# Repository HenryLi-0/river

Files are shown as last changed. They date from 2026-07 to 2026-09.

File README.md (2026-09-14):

<div align="center">
    <h2>River</h2>
    <p>by <a href= "https://github.com/HenryLi-0/river"> @HenryLi-0 </a></p>
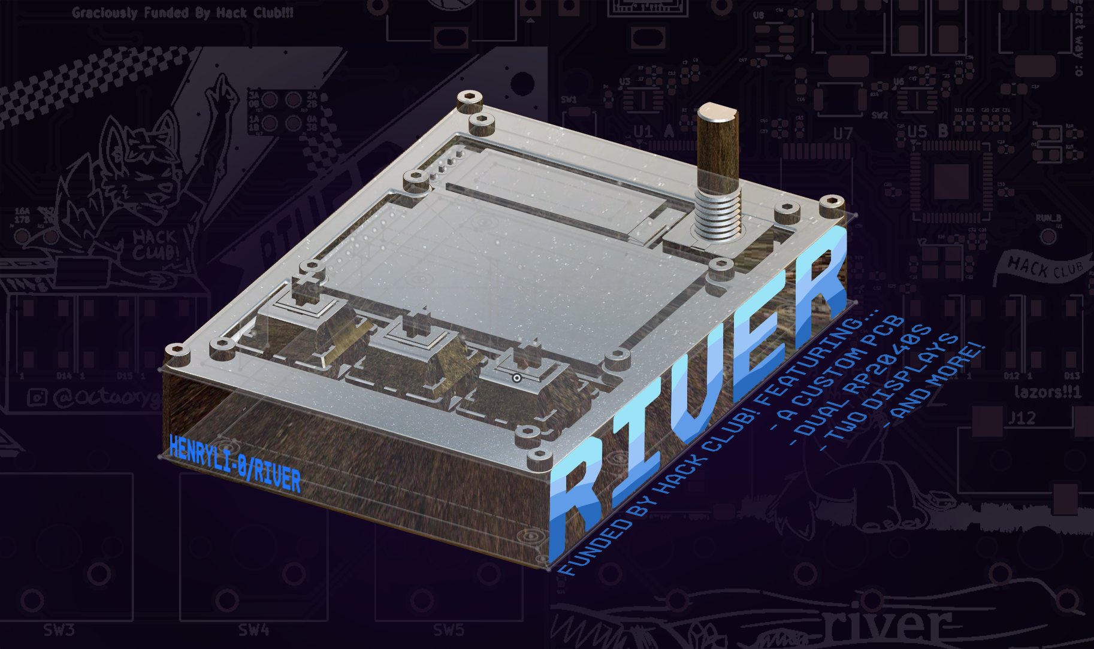
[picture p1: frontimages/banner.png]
banner
    
</div>

<sub>All designs are open source! Hardware licensed under CERN OHL S v2.<sub>

# River

a quick stepping stone

---

## What this?

A couple of months ago, after listening to [archived](https://archive.org/details/the-sport-saver?webamp=default) [music](https://archive.org/details/under-the-ground?webamp=default) on the Internet Archive with Webamp, I thought the graphics on the right side (powered by Milkdrop) were pretty cool. I've always liked how Geometry Dash levels *typically* have well synced gameplay, since it's just so satisfying. Additionally, I also dislike how everything is switching to streamsing services (both because of the subscription model and more importantly the amount of cellular data it uses lol), so I basically wanted to bring music-synced graphics onto a portable offline device!

So, River is a relatively small PCB, hosting a dual RP2040 setup, each having custom firmware! The first one handles all the user controls, file loading, and the audio jack, while the second handles the display math, communicating with the first RP2040 by SPI and UART. Through this (rather unconventional) setup, audio can play continously while the second RP2040 works on more taxing graphics using the Pico SDK for C, with the second RP2040 basically just doing the graphics. It does this by having a PCM5101A and a TPA6132A2RTE into a TRS audio jack!

In retrospect, this project wasn't exactly a quick stepping stone (as in, it took over fifty hours of development), but it sure did review many topics surrounding PCB design with KiCAD, building on to what I learned from Hackpad and Raven! Originally, this was in case [fermion](http://github.com/HenryLi-0/fermion) would require a custom PCB, but who knows if it'll need one in the end. Anyways, working on River did teach a lot, as well as letting me have fun creating art for it!

---

Huge thanks to [this](https://blueprint.hackclub.com/starter-projects/devboard) guide from Blueprint and [this](https://pip-assets.raspberrypi.com/categories/814-rp2040/documents/RP-008279-DS-1-hardware-design-with-rp2040.pdf) documentation from Raspberry Pi for valuable information on RP2040 wiring design. Thanks!

---

## Pictures!

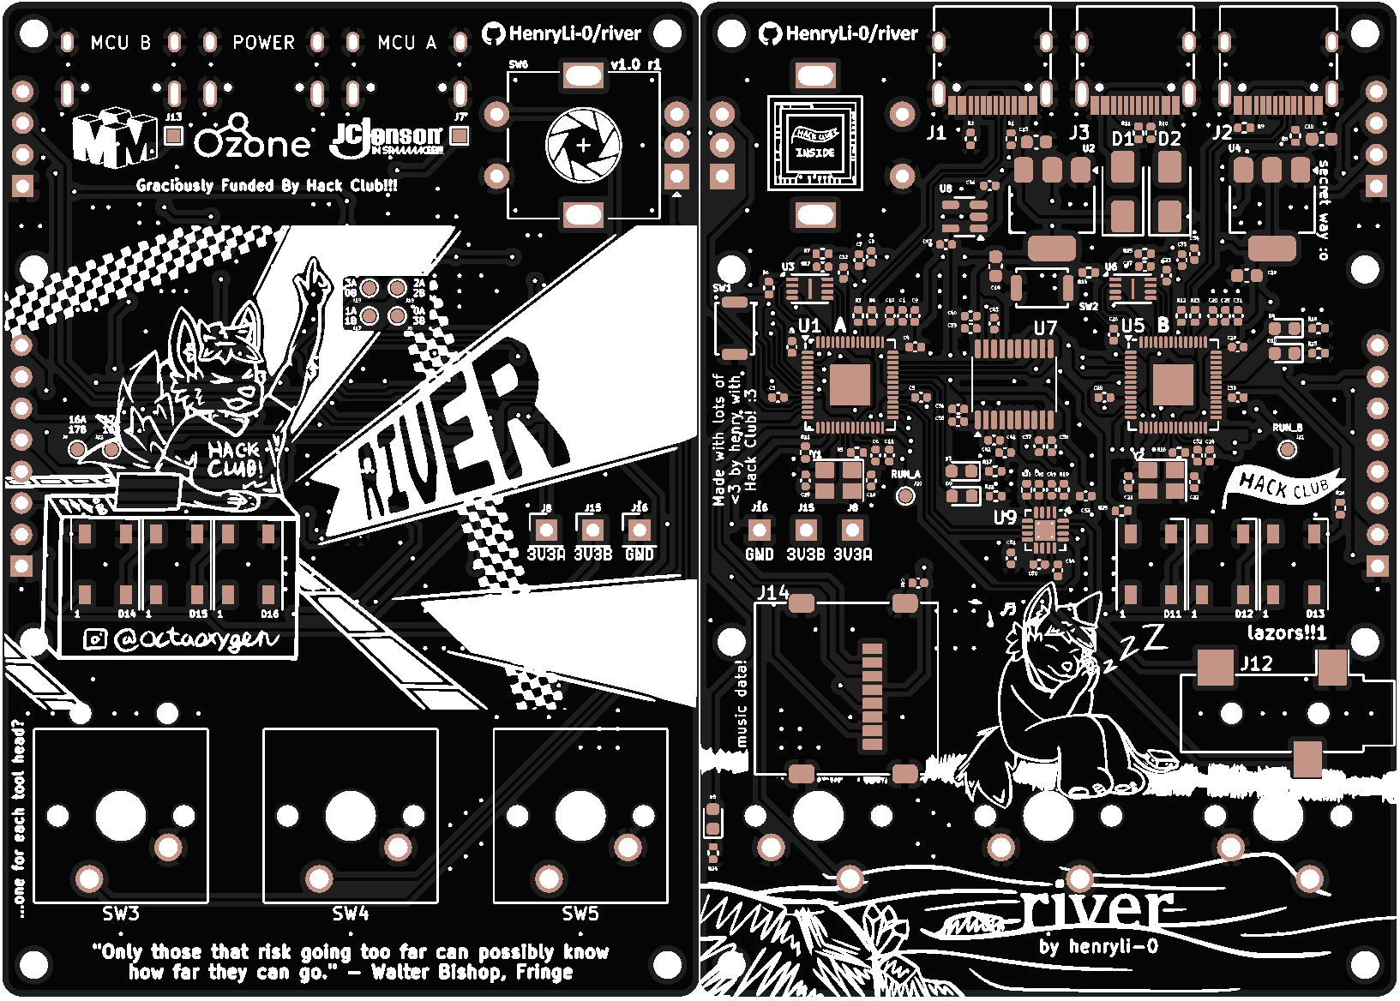
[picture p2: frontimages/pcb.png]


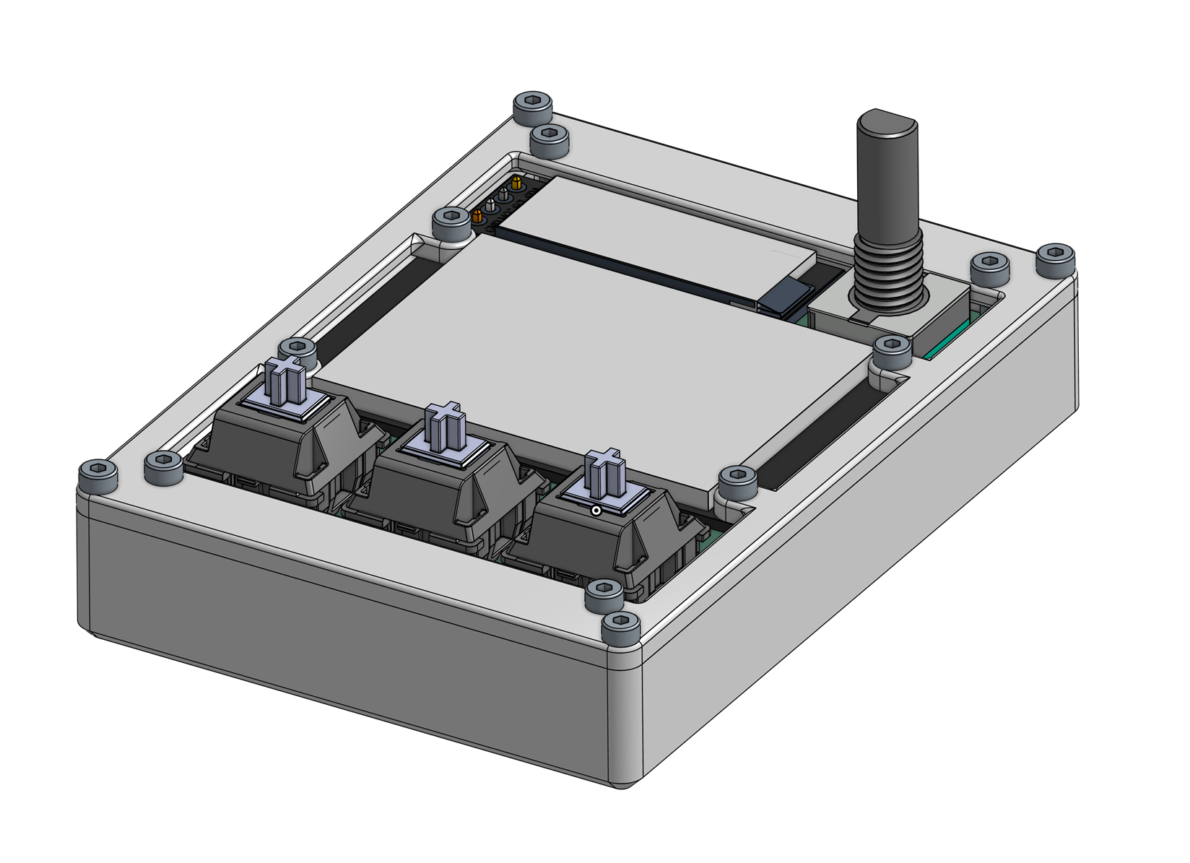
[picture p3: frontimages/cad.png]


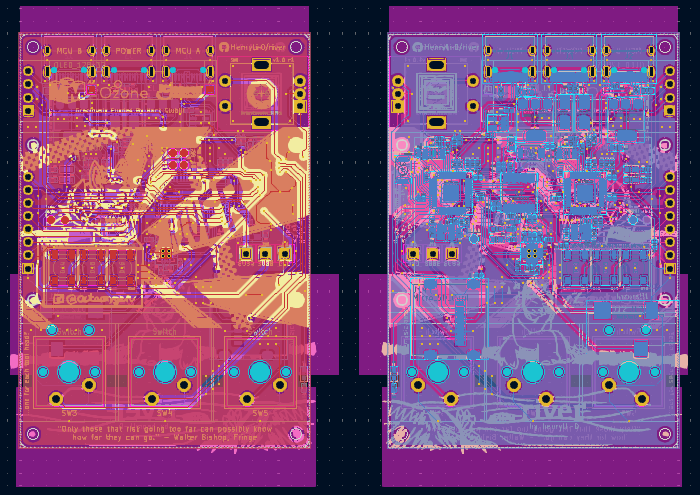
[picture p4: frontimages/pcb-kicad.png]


---

## Directory

- [CAD](</cad/README.md>)
    - The case is made in Onshape!
- [Firmware](</firmware/README.md>)
    - Two firmwares for the two RP2040s!
- [Updatelogs](</updatelogs/>)
    - As always, lots of behind the scenes content! It's also a decently long read as always :D
- [BOM](</BOM.csv>)
    - Want to build one yourself? Here's the BOM in CSV form! However, I suggest using the Google Sheets one, check down below for that!

---

## Usage

Assembly
1. First, one must obtain the PCB! It's not really made for hand-soldering, more so for JLCPCB's or any other PCBA service to assemble (but feel free to give it a try if super experienced!).
2. The main PCB's here? Great! Flash the two RP2040s with their specific firmwares and make sure all status LEDs and storage works! (Same process as testing a devboard, except there's not really any free pins...)
3. Once the RP2040s are confirmed to be in good condition, test the micro SD card slot and the audio jack! A micro SD card and a TRS audio plug (usually in random earbuds) are needed! Load music on and see if it works (after setting the firmware to play a song from the micro SD card).
4. Once those also work, solder on the displays and keys! This should be fairly straightforward, watch a soldering tutorial if needed! (Yes, a soldering iron is also needed!)
5. Assemble everything into the case and screw in the M2 screws! Adjust the case if needed if the audio plug doesn't fit well with the current slot!

---

## BOM

Note: This list was made in mid-September 2026. Depending on a ton of factors, this price may change over time, so these prices may be different! Multiple parts are sourced by me (since I have a bunch of extra parts laying around), so it will likely cost a bit more. Currently, shipping and tax estimates are included (to NYC), check out the `updatelogs` whenever construction occurs to find the actual price it resulted in!

[Here's](https://docs.google.com/spreadsheets/d/1_4eaDKRTe7VvPdyKRilJCp6rfzp3SGLLEaJtn6RHo0M/edit?gid=0#gid=0) the original Google Sheets BOM, color coded too! (It'll also be more updated, but I'll try to sync this one too!)

| Part | Price | Link |
|---|---|---|
| Board PCB (PCBA) | $84.61 | JLCPCB |
| M2 Screws (16mm, 50pcs) | $1.41 | [AliExpress](https://www.aliexpress.us/item/3256804341271555.html) |
| 128x32 OLED Display (White, 1pc) | $2.44 | [AliExpress](https://www.aliexpress.us/item/3256808453793642.html) |
| 128x160 TFT Display (1.8 inch TFT) | $4.06 | [AliExpress](https://www.aliexpress.us/item/3256807859088652.html) |
| WS2812B LEDs (3) | $0.00 | Anywhere |
| Micro SD Card (1) | $0.00 | Anywhere |
| EC11 Rotary Encoder (1) | $0.00 | Anywhere |
| Cherry MX Switch (3) | $0.00 | Anywhere |
| Estimated Shipping (JLCPCB to NYC) | $11.05 | JLCPCB |
| Estimated Shipping (AliExpress to NYC) | $0.00 | AliExpress |
| Buffer | $5.00 | |
| TOTAL | $108.57 | |

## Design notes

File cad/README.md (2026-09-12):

# CAD

Check out the CAD, made in Onshape, over [here](https://cad.onshape.com/documents/62a670f78dfbc39c10baf690/w/2a64289aedb28fbfcb5cf3fe/e/198c185c06bddf69967ad1b8)! The `.STEP` file is also in this directory, if needed! (Note that the Onshape document will be more updated! The export date for the file is in the name!)

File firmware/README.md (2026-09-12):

# Firmware

As always, firmware is kinda difficult to write without the actual board to rapidly test, but here's a couple test and concepts for the actual firmware!

*Note: As of mid-September 2026, these firmwares are incomplete for previously mention reasons! (If you're somehow reading this, this would be a fun challenge to do if you're up to it! It's fairly straightforward if you have the parts!)*
- [MCU_A](</firmware/mcu_a/README.md>)
    - `MCU A` firmware! This is the one that does the controls and audio stuff!
- [MCU_B](</firmware/mcu_b/README.md>)
    - `MCU B` firmware! This is the one that does the big display stuff!
- [Test](</firmware/test/>)
    - Lots of test firmwares, good for testing stuff!

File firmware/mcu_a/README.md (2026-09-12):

# MCU A

This RP2040 is responsible for managing user inputs, the smaller display, loading and playing music, as well as transmitting song information to `MCU B`!

Here's the pins:
- 0-3: SPI0 MCU
- 4-10: Buttons
- 11-14: Micro SD Card
- 16-17: UART0 MCU (backup)
- 18-19: OLED 128x32 Display
- 23-25: RGB, Board, Boot LEDS
- 20-22, 26-28: Audio

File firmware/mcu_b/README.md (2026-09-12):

# MCU B

This RP2040 is responsible for displaying the graphics on the central display, after receiving song information to `MCU A`!

Here's the pins:
- 0-3: SPI0 MCU
- 8-13: LCD 128x160 Display
- 16-17: UART0 MCU (backup)
- 23-25: RGB, Board, Boot LEDS

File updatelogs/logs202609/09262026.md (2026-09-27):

# 9/26/2026 - 21st Update!

welcome back! yes, i know, fermion hasnt gotten an update in like two days, but hey, we're back for a bit here! why?

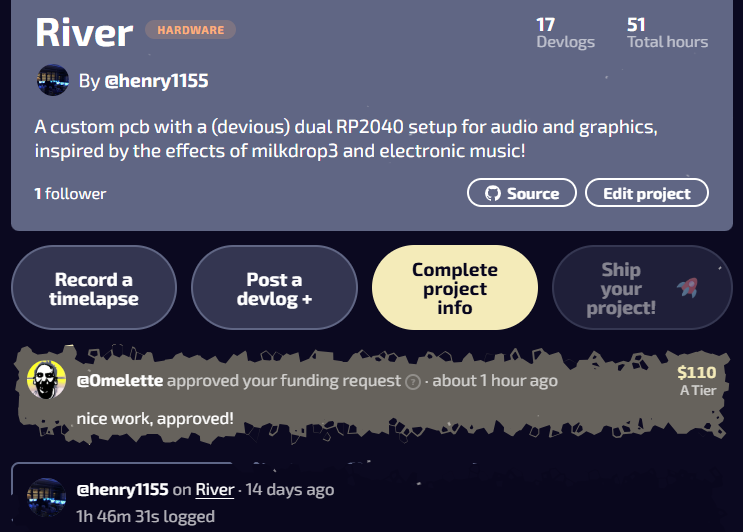
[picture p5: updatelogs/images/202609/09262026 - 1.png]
woo


as always, this means i gotta lock in and get the stuff ordered today! (originally i saw the picture like 6 minutes after it came out, but i had to do a little work before getting here!)

well, it's actually 6:52 PM at 9/26/2026 now, that stuff up there was from yesterday night, i just didnt start last night. anyways, here we go! (additionally, i think i know why my hand hurts now, turns out slamming your hand into the table is not a good idea)

anyways, ordering time

so uh. jlcpcb. why is the summary page different from the checkout page by >$40. 

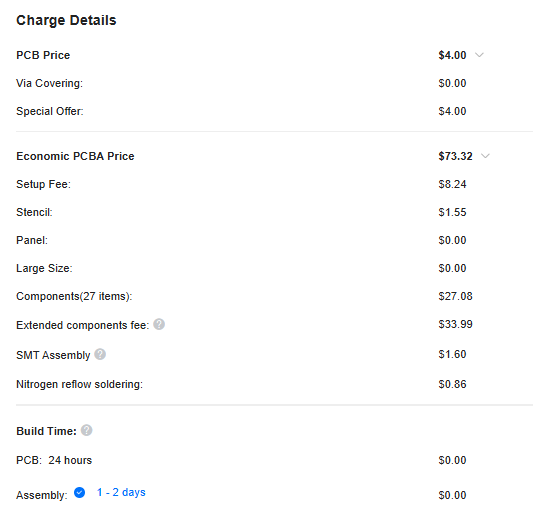
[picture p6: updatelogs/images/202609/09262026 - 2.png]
erm


optimizng bom part 2

ok, it's 7:36 PM, this isnt gonna work, brb.

yeah, so idk what to do now. like, theres literally not much i can do, i optimized it to be a grand total of $7 less.

since when did global direct shipping line... oh wait thats cm not mm, i was gonna explode for a second

ok, so seems like the goal is to somehow reduce our bom for the pcb itself from $73.32 (already down from like $80 something) to be less than $59 somehow. yeah. thats not really happening...

where did my coupon go

i mean, either way we gotta shave $40 off our bom somehow here. which is very much impossible and not happening.

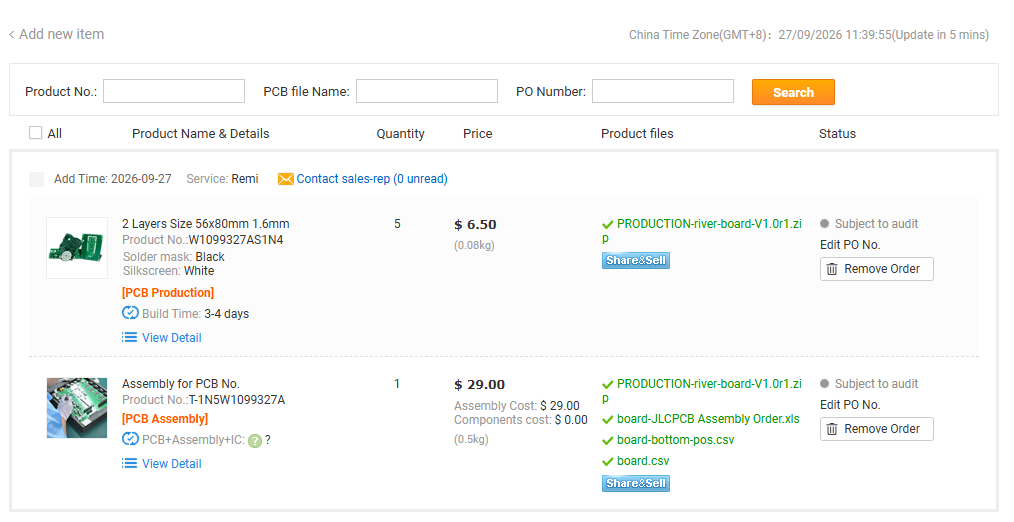
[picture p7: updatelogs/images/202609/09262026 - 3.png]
hmm


ive moved it to pcbway (hopefully), files are under review but im hoping that, even if shipping and customs are still mad high, that at least only have one board assembled will cut enough on price? idk though.

well, that said, see ya in like a week or whenever they review it! it's 11:43 PM and yeah, see ya! ill be over at fermion in a second, so yeah, good night!

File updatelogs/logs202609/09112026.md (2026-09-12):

# 9/11/2026 - 20th Update!

well, it's 10:17 PM, lets get to it!

a while before i updated the background of the banner so its darker and added a glow, thought it made things look a bit better? idk

anyways, bom time, more like everything time, what do we have left to do?

- test code (bare sample)
- cad double check and export
- update bom (add M2 screws, double check)
- ship???

so yeah, let's get that done tonight!

well, you know my main source for all screws :p ([here](https://www.aliexpress.us/item/3256804341271555.html) on aliexpress!)

ok, bom should be good, cad should be good, exporting...

ok, another banner update! it now has the pcb in the background! (faded, of course!)

ok, it's 11:56 PM now, gonna quickly commit, did a ton of docs, readme stuff, bom stuff, basically i think (might be missing something?) mostly everythings ready except for the firmware!

well, tried my best, really cant write the firmware right now, its kinda weird to do it without constantly flashing and testing it (yeah, its not optimal, but still, thats my favorite way to do it)

ok, a bit more clean up work, i think we're ready to ship!

*The rushing torrent of water. It's rushing and rushing, basking below a warm summer sun, except the water keeps rushing, streaming as a tidal wave rather than a river. It's fast, almost unstoppable, gushing as it passes by.*

*The torrent's calming! Quick, swim to the side! And indeed it was. After nearly two months, bobbing, rather, tumbling, through the crashing flow of the waters, it found its rhythm. Swimming to the shore, this adventure, has come to an end, and a considerably unfamiliar land presents itself, much different than the place upstream...*

ok, it's 12:22 AM now, gonna move this to the website so its updated with today's stuff! hope you enjoyed that little bit of writing, and yeah, for now, good night!

hey its 1:13 AM and im back, added some basic firmware stuff so its more than a blinking led, still gotta work on it a bit, also updated the readme with the audio part names but yeah, for now, good night!

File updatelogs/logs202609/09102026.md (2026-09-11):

# 9/10/2026 - 19th Update!

ok, 10:42 PM, wow, we're locked in tonight!

no time to waste, to onshape!

wow got started so fast i forgot to post last updates log to the site, one second... ok, back to onshape!

ok, here it is!

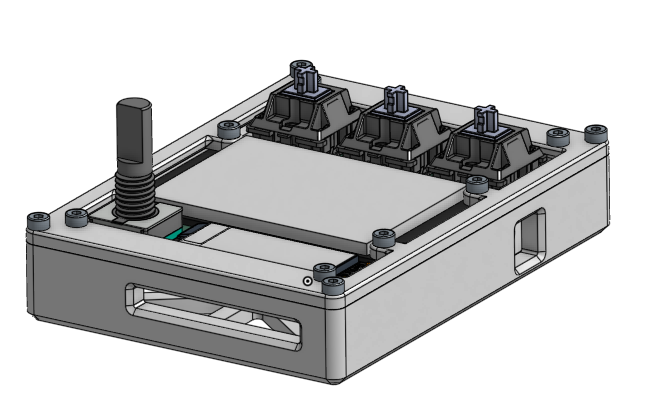
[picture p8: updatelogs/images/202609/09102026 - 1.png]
waw


added the port holes and stuff, did a couple checks, it should be ok? of course, the cad can be adjusted when the actually parts arrive! anyways, exporting stuff so that i can make a thing for this!

so some how i only have 6.7GB of storage left. kinda funny but not very good, ill deal with that later...

ok, good amount of work today! wrapped up the cad work it seems, also did some banner stuff! (check the readme!)

anyways, i think i need another day for this, with that said, it's 12:24 AM, and yeah, good night!

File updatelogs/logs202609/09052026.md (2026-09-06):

# 9/5/2026 - 18th Update!

ok, it's 9:28 PM, they rejected the part request (lel) back on like 8/28/2026, yeah its been a week

anyways, lets finish this one up?

ignore the bottom right corner if youre on lookout, idk if it even records it but i need to watch a video right now

anyways gonna change the sd card footprint thing now

nvm dont need to watch this video i guess

ok, should be replaced, gonna double check it has a model

ok, it does, just came back after a quick half hour break (well thats not quick), 10:40 PM and checking for errors...

ok, 10:56 PM, it should be good! added a couple more vias for ground stuff, gonna commit and prepare to export!

ok, back at 11:38 PM, let's export!

(also for reference [this](https://jlcpcb.com/partdetail/MOLEX-472192001/C164170) is the jlcpcb part for the microsd card) anyways, all exported, doing jlcpcb stuff now!

ok, stuff should be moved over, time to go to placement!

well, seems good now?

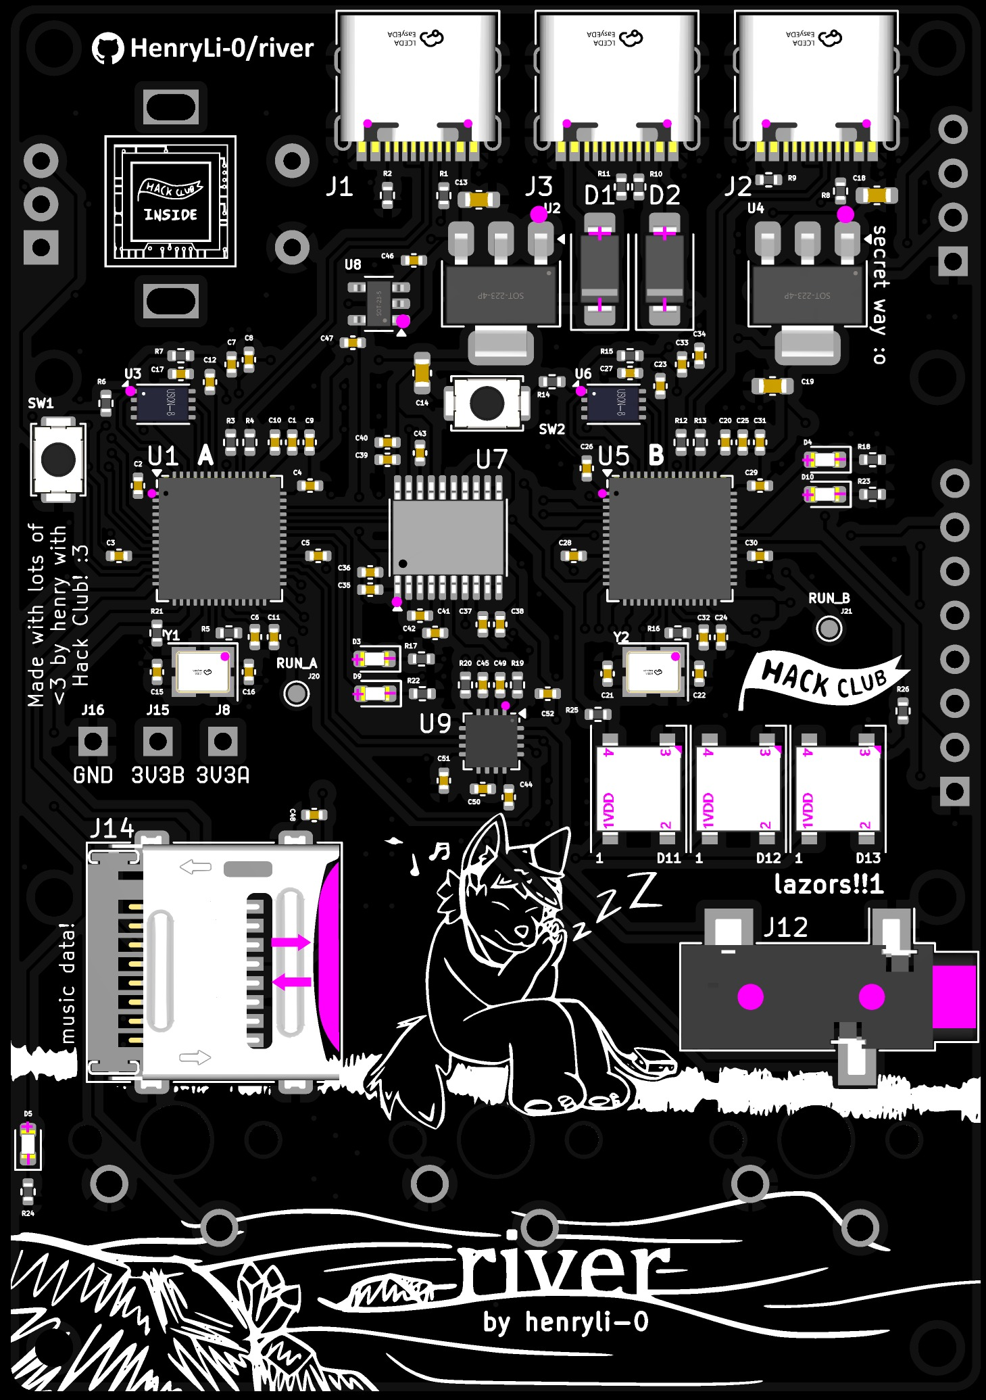
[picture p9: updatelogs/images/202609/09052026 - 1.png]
waw


huh looks like jlcpcb got an update some time recently, anyways, after comparing images, looks good!

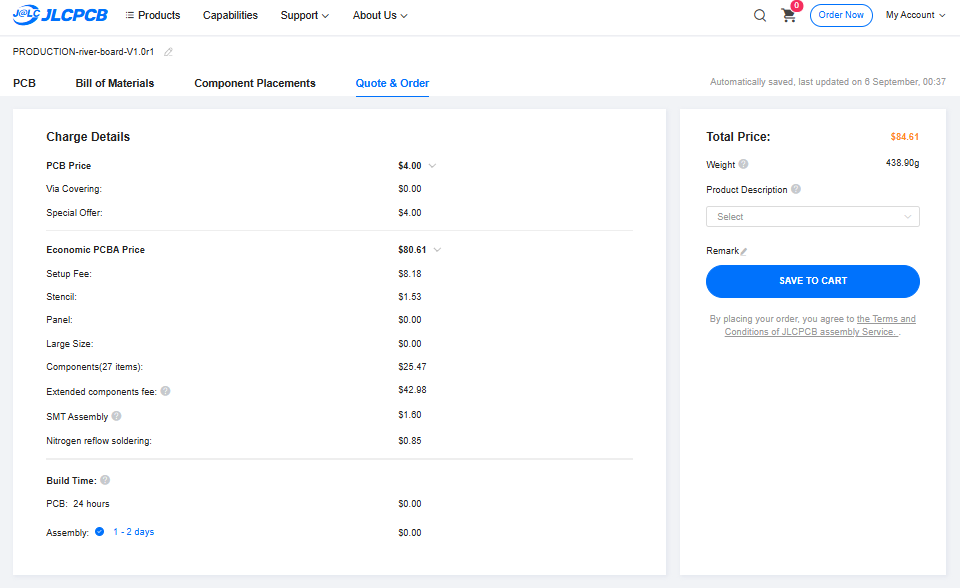
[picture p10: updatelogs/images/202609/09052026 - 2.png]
hmm


hmm

well, ggs! the boards good to go it seems!

quick commit

well, now all we need to do is clean up the repository and prepare to ship! (and some test code, cant really do much right now, of course)

ok its been like half an hour, havent done much, i think im gonna end it here! so yeah, shipping and maybe updating the cad is the only thing really left (oh wait and screws for the bom), so yeah, it's 1:14 AM, good night!

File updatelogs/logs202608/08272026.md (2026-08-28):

# 8/27/2026 - 17th Update!

ok, 10:39 PM, lets speed through this!

ok, quite a bit of rotating stuff on jlcpcb's side, but here it is!

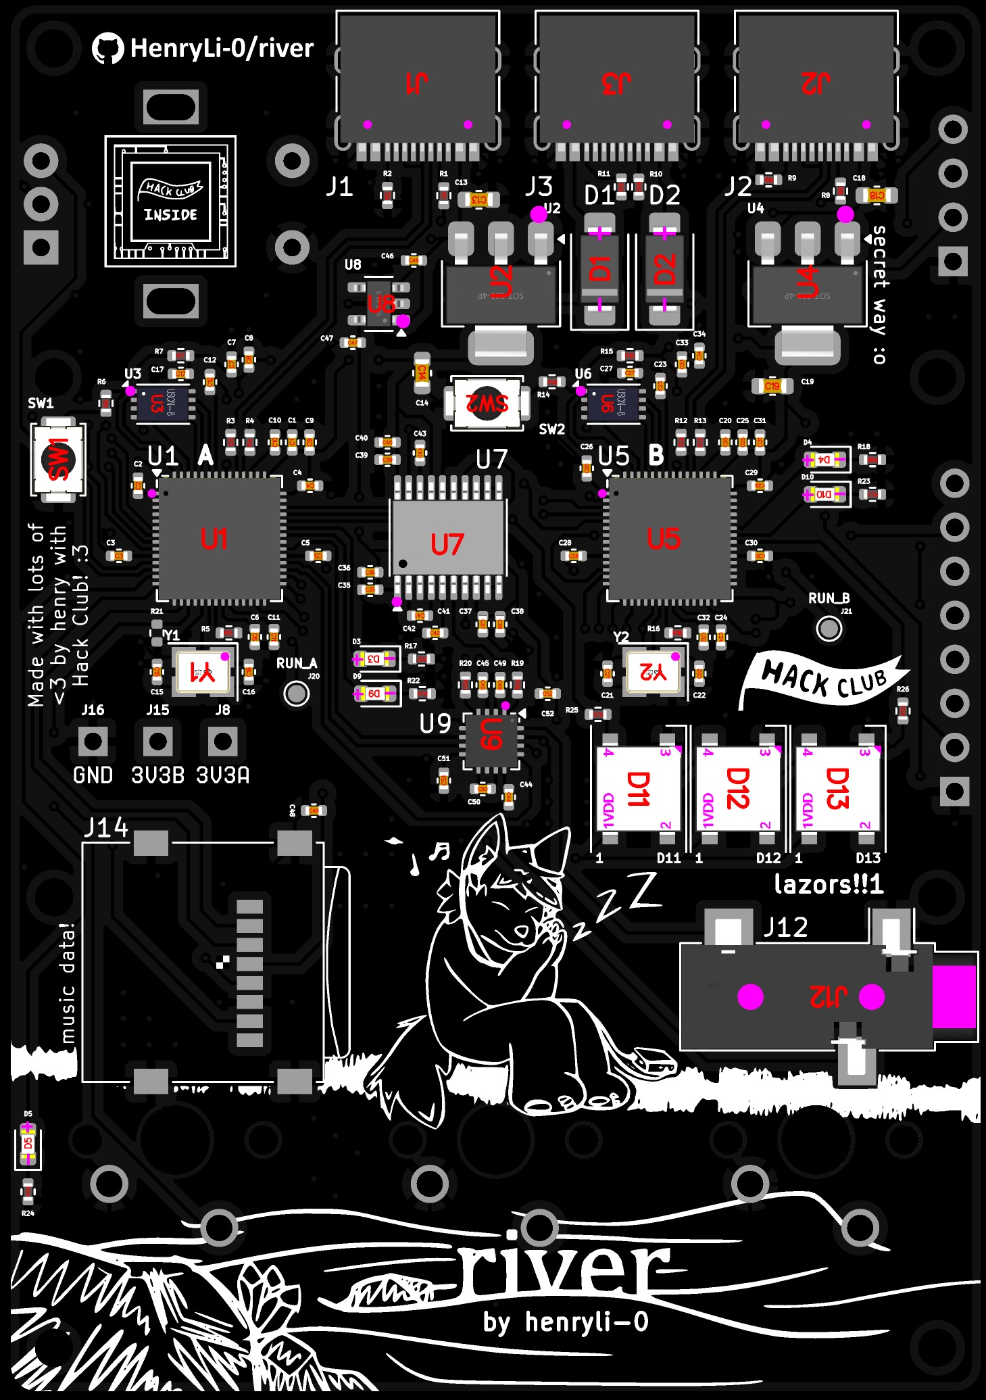
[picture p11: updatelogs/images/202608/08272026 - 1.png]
hmm


it should mostly be good? only thing im not sure of is the crystal but yeah!

hopefully when i reload the page it saves...

no it doesnt. well, thats annoying.

well, 11:21 PM, made an application for the sd card thing to actually get a model, so yeah, not much i can do today, unfortunately? just kididng, cad could use some work, brb

ok, 11:47 PM, im back!

shrunk the middle section from 1.4cm to 0.75cm! nvm its back at 0.95cm, anyways, total height decreased from 2.1cm to 1.5cm! ok, 11:54 PM, brb!

back at 12:44 AM, i guess its a good time to assemble a bom? (for the other parts)

well, 1:07 AM, that wasnt really much... yeah, gotta wait till the 3d model for the micro sd card slot appears or i just gotta replace it, idk, but yeah, i guess ill check tomorrow evening, if its not there, i guess ill just replace it? but yeah, 1:21 AM now (yes i got distracted), so yeah, good night!

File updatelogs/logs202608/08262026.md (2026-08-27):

# 8/26/2026 - 16th Update!

well, welcome back, it's 3:00 PM here in nyc right now, a bit of a warm day, i kinda want to get this done, its taken far too long (its been a month already?). i kinda have more important things to sort out, but they can wait a bit, they're not like extremely time sensitive!

ok, 3:10 PM, im actually back now, ive been considering removing the encoder (yet itll look crazy weird, i know), imo, most features should be still possible without it, just a bit more annoying to navigate with long presses and stuff, idk.

eh, whatever, im gonna first play around with the layout to see if its possible first

ok, audio jack moved to the bottom (and added the 3d model!), lets run drc... uh, suspiciously no error?

quick commit!

had a great idea (flipping the switches upside down for more space)

uh it would probably be better to keep the data lines short right

hold on did i reverse the audio jack direction... anyways, 5:10 PM, micro sd card is there and all drc errors fixed! gonna commit real quick and then run to the bathroom...

ok, 5:38 PM and back!

ok, did a bunch of via stuff so all the grounds are more connected, fixed up some silkscreen text, the only thing really left is to fix the silkscreen art stuff, but yeah!

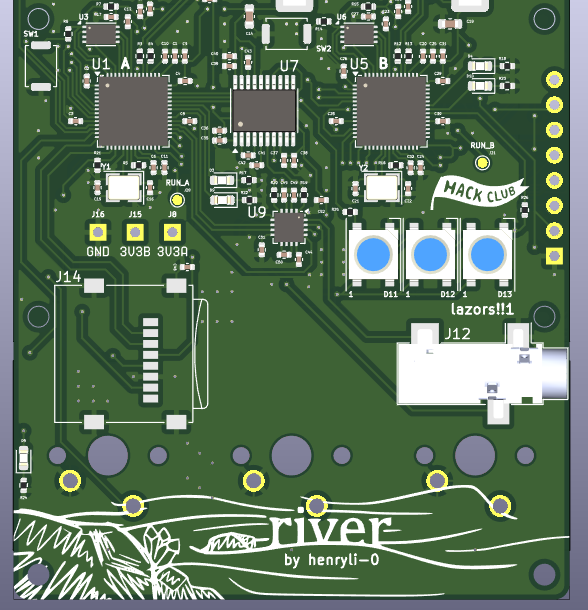
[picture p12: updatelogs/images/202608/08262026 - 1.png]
waw


so yeah! gotta double check that audio jack direction again (it should be correct now?), but yeah, it's 6:33 PM, off to dinner, brb!

9:48 PM, did a good amount of work off camera fixing the silkscreen and stuff, but yeah, pretty happy with where it is now! could probably start exporting stuff now? gonna quickly commit first though...

oh yeah, also checked the length of the traces that should be equal (usb c connections), they're still good!

ok, 11:32 PM, im back for a bit, time to export stuff! (again!)

12:23 AM, lots of part picking, gonna brb!

im back at 1:53 AM, lets quickly finish this up!

i really cant find an led that works. well, had a little help, but C524052 works!!! 

well, that said, it's 2:43 AM, the bom has been exported and should be there, im gonna go to sleep now, gotta wake up earlier tomorrow for something, so yeah, good night!

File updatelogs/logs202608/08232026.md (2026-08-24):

# 8/23/2026 - 15th Update!

so. how much silkscreen art can someone make? turns out, not enough, but i think im at the point where im mostly satisfied with the decoration and the layout, in theory, we can kinda finish everything today? it's 6:01 PM right now in nyc, im just gonna get ready to post yesterday's (well, two days ago's) updatelog onto the website

oh yeah, another cool thing, i figured out how to fix my s key! its staying in there pretty well so far, so let's see how it holds up...

ok, ive posted it there, what do we have left?

- finish the pcb clean up (not much, really, just notes and checks)
- drc again, check its all updated and good
- export and do the jlcpcb stuff, create and calculate bom/prices
- decide whether or not to use female headers for the removable screen
    - on one side is the audio jack, repairability and, well, the art
    - on the other side is increased height and possible connection issues
    - its really just that the audio jack probably doesnt fit
- make the side heights readable (this cad is abysmal)

well, what are we waiting for? let's get to it!

i, in fact, did not lock in. just kidding!

[this](https://www.aliexpress.us/item/2255800687544049.html) looks good for the header stuff i was talking about, id say the screws should also be able to secure everything, so thats another plus!

quick commit, one second

ok, 7:35 PM now, gonna go to dinner now, lots of cad work!

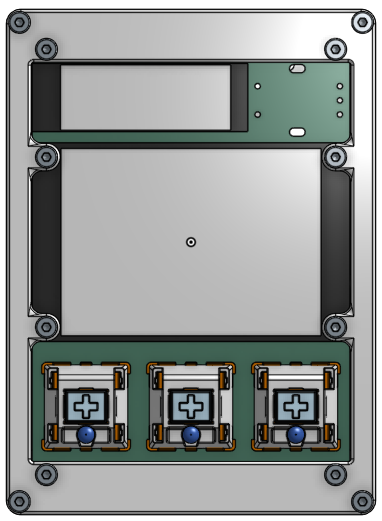
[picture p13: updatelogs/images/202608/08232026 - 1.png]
hmm


ok, see ya in a bit!

back at 10:57 PM, let's just finish this :p

so. i just realized something.

it's not a good realization.

the sd card is on the top.

the microphone jacks is on the top, that's fine, but the sd card holder is on the top. why is this an issue? well, i was particularly avoiding double sided assembly for the costs. and then i forget about this.

i guess we cant avoid it then, 11:44 PM, these docs are confusing

im back at 1:52 AM, im gonna try this again

thanks to [this](https://jlcpcb.com/help/article/how-to-generate-gerber-and-drill-files-in-kicad-8) help article! i guess doing it manually instead of the fabrication toolkit or something back with hackpad was needed...

ok, 2:15 AM, im basically not able to do anything right now. im pretty sure i cant keep going with standard pcba, since it gets crazy expensive (yeah, im trying to not make it super expensive) and it has some weird setup thing that i really dont want to figure out (something about adding extra rails to the side? i mean, thats not optimal here). so yeah, i cant do anything for now. what that means is that i have to do a ton of redesigning, specifically moving the sd card and audio jack to the bottom (maybe ill remove the encoder for it??? who knows), and of course the leds (just kidding, maybe the resistor, but the rest is staying on top! ill just have to do some (abysmal) hand soldering...)

so yeah. that's where things are at, it seems. ill probably have to remove the female pin header row and just direct solder it then? but yeah, that's it for now. well, i guess theres more to do know, it's 2:21 AM, so yeah, good night!

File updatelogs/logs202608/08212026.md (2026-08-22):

# 8/21/2026 - 14th Update!

so... where have i been? it's 10:51 PM, one second...

though it may appear like ive locked out, ive spent like a least three hours drawing the silkscreen stuffs!

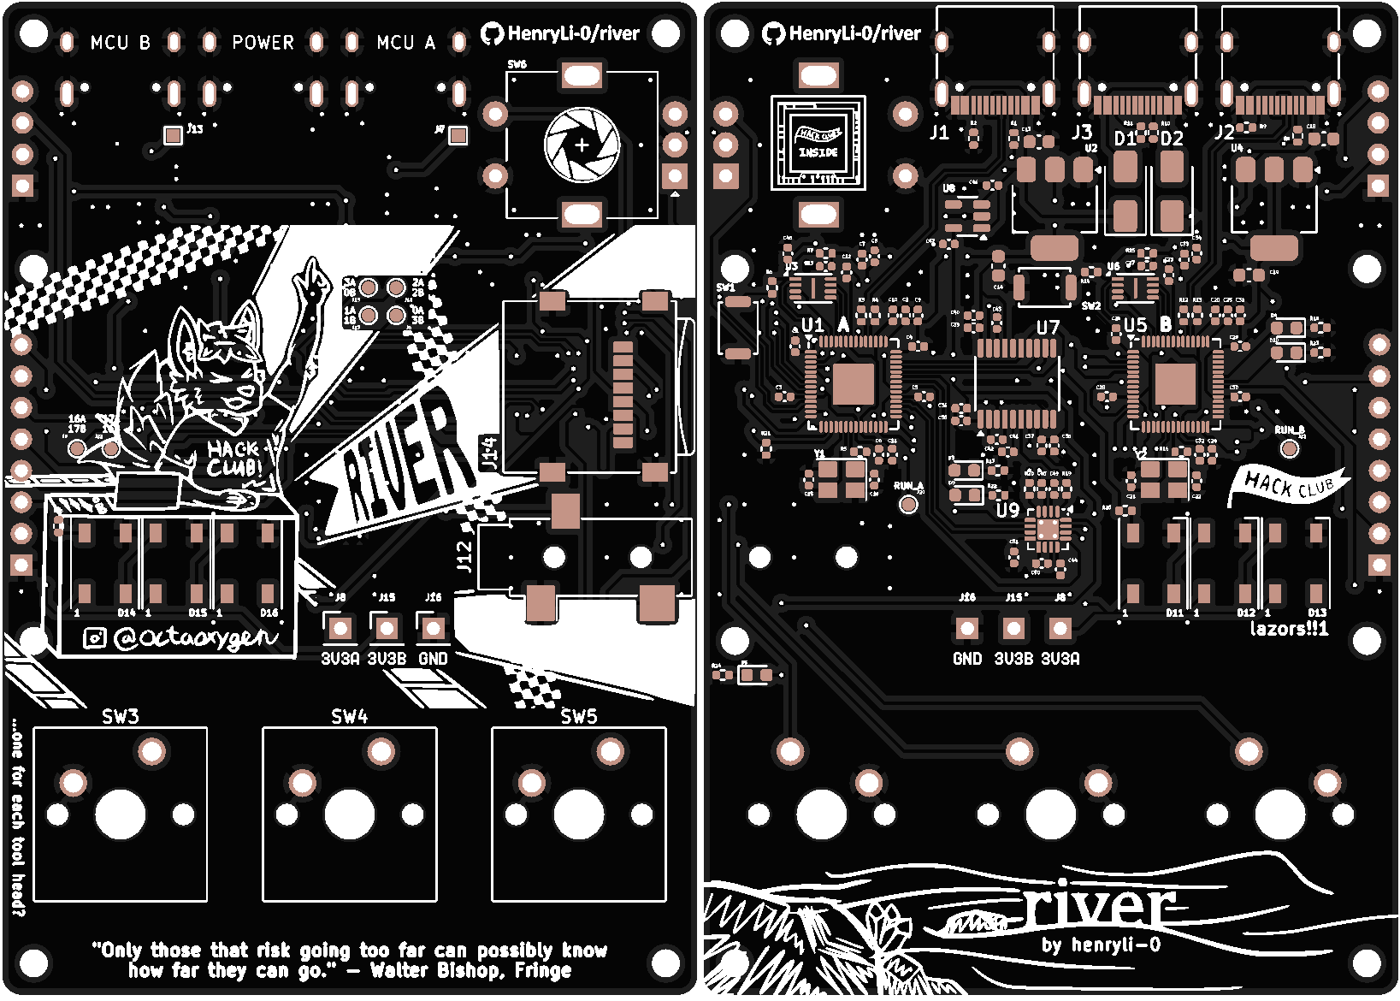
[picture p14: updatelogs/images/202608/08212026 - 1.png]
waw


yeah! looks pretty nice, along with that, fixed a whole bunch of errors and warnings, so now, the only warning are just silkscreen stuffs (and that the debug pins arent connected). also, yeah, added the run pads, idk how useful that is, also, the only warnings right now are that and the fact that we had to make one of the audio chip holes bigger (shouldnt be a problem i hope? i mean, the things are already connected so...)

might have to look into that one

anyways, yeah! added more vias here and there, cleaned stuff up a bit! mostly was working on silkscreen art, probably shouldve timelapsed it but its really whatever, idk if it wouldve counted anyways, but yeah

so... what now? yeah, tha's pretty much an update of where ive been, idk what happened the third day i wasnt here, i think a reasonable goal is shipping this by the end of the month, then fermion work starts

brb!

ok, back at 2:40 AM, obviously not an eventful day and more of a catch up and commit thing, snuck in a couple more jokes and references, they're under the oled! (the 128x32 display, not the other one) well, that's it for me today! it's 2:41 AM, so good night!

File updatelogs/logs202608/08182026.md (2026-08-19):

# 8/18/2026 - 13th Update!

a little later, but here nevertheless! it's 10:02 PM in nyc, and yeah, here we go! goal today is to mostly (???) finish the pcb!

so uh, i ran drc and the whole thing froze, 73 errors and 200 warnings, wow, anyways, most of the stuff is complete! well, issues aside, we still have to add the test points and stuff, but yeah, good progress! it's currently 11:40 PM, gonna brb!

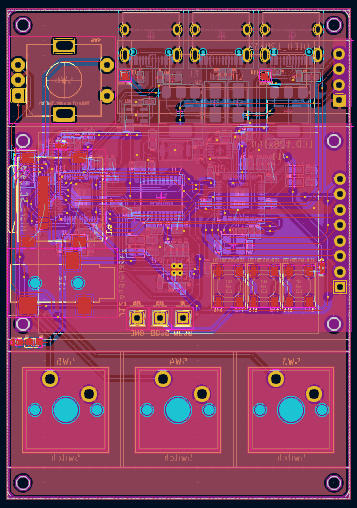
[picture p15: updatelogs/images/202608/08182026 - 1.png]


via spam go brr, anyways, yeah, see ya in a bit!

back at 1:23 AM, yeah, earlier than usual, back to pcb work!

so i kinda dont have anywhere to place the test/debug pins. yeah.

well, 3:10 AM, all DRC errors solved! theres some goofy shenanigans to get U9 to have the thermal relief to zone incomplete error to go away, but its really whatever, nothing really changes about the real area! now, we have a ton of warnings (lots of them are about silkscreen size), but its really whatever, its more for aesthetics anyways, at least the smaller text!

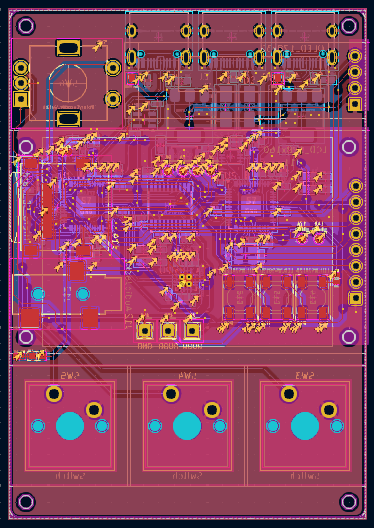
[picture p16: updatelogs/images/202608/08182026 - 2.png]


so yeah! i think thats a good place to end for today, that said, it's 3:14 AM (wow, pi digits huh?), so good night!

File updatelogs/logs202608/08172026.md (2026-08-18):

# 8/17/2026 - 12th Update!

is bro actually locked in? 8:55 PM today, the goal's to finish most of the pcb today! which would kinda be insane

good news! its the right connector. bad news? its kinda too big in the current setup. so yeah. 

we have three choices
- flip the rp2040 into the middle
    - lots of moving and redesigning i dont really want to do
    - increased chance of hitting the things on the bottom of the display
    - silkscreen on the bottom would be cooler
- make the center thicker
    - makes the entire thing bigger, idk
- move the rp2040s closer
    - makes size stuff tricky/annoying to deal with
- evil upside stuff
    - probably the best but definitely the most jank solution
    - shouldnt do it since its not really designed for it

so i. uh. dont understand my own cad. why did i make this so unreadable

i think making the center thicker is the best choice here

sd card wired, idk how necessary similar trace lengths are needed, but i did it within 5mm so it should be alright according to some random sources?

ok, 2 hours later, it's 10:57 PM! the audio stuff is wired together, havent added it to the rp2040 yet, it's kinda a bit wonky right now, might need to rotate the stuff to properly add it, so yeah! 

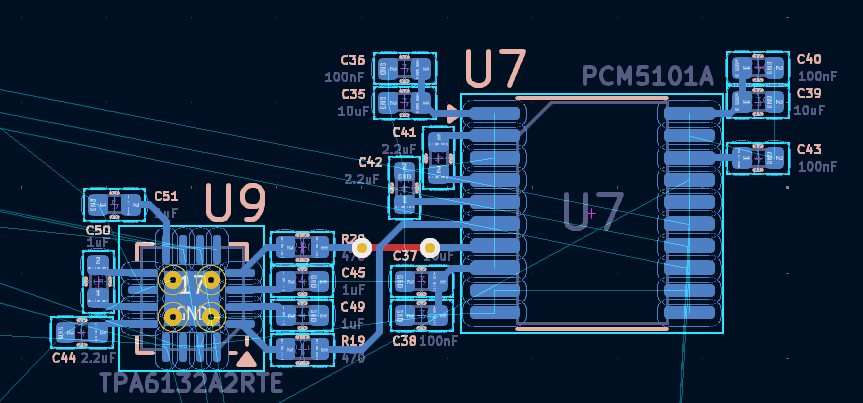
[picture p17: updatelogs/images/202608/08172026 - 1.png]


ok, gonna brb!

some three hours later and back! it's 1:51 AM, let's lock in real quick

another bit more than 2 hours later, a ton of stuffs wired up! mcu communication and displays, the audios to the mcu pins, buttons, and more!

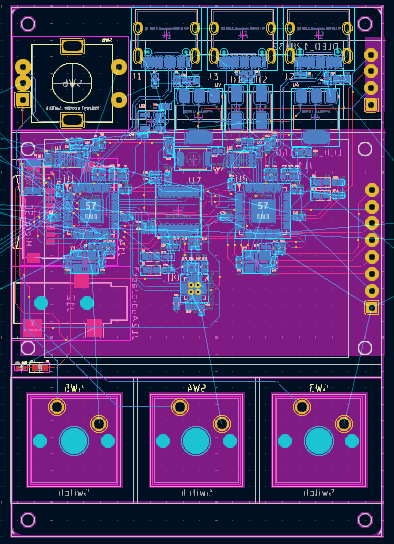
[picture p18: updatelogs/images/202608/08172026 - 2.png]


so yeah! good progress today, that said, it's super late now, since it's 3:59 AM, so yeah, good night!

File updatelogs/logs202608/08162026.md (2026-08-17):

# 8/16/2026 - 11th Update!

ok, 6:23 PM, and some 10 days later, the one week project turned into three, yeah, i got demotivated again

however, after practicing jumpstyle out of nowhere, something flipped in my head and now i just wanna lock in. yeah. thats really the only reason why im back lol. anyways, pcb time, im thinking that we dont really need to expose so many pins, but its ok if we need to 

vscode looking a little different today. huh. anyways, pcb time

ok, the base is done! all the holes should be laid out, added some extra effort and added curved edges!

wow, 10:42 PM! 4 hours and 10 minutes later, straight lock in and pcb work, mcu a is done! at least, mostly done, havent double checked for issues yet

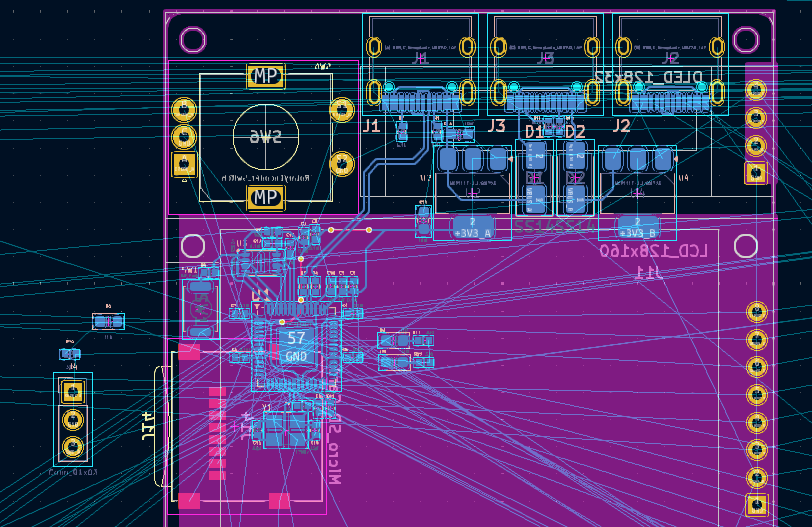
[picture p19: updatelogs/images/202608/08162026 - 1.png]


so yeah, gonna go watch a movie, brb!

2:13 AM and back, here we go! ok a bit thirsty, pretty sure that the tap water here in nyc is very good, anyways, its a nice cool rainy night here in nyc!

so uh, idk if theres a faster way to like copy paste what i just did

ok, 1 hour and some 37 minutes later, it's nearing 4am (it's 3:55 AM), so i think here's a good place to end! great lock in today, around 6 hours of work done!

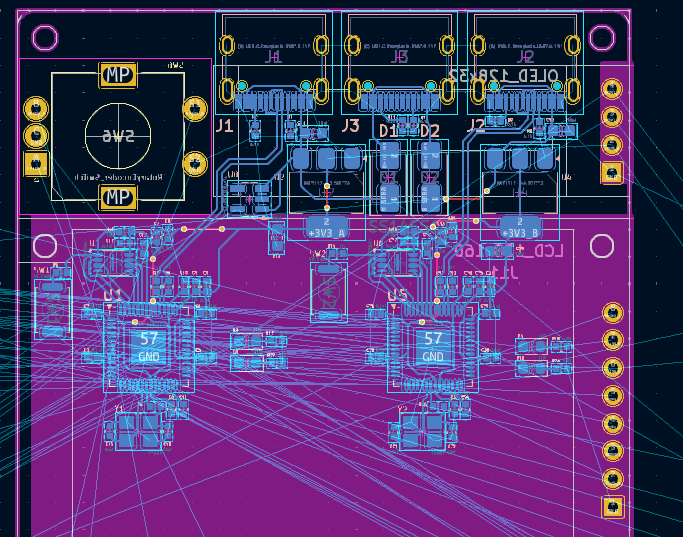
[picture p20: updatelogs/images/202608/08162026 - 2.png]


so yeah! that's pretty nice, good start to pcb stuff, should go pretty smoothly from here? idk lol, anyways, it's 3:58 AM, good night!

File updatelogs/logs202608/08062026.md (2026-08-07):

# 8/6/2026 - 10th Update!

double digits uh oh, 9:37 PM, gotta go fast (sonic reference?)

we do need a schottky diode (like a specific one) (no way, did i spell that right? wow)

ok, lots of things assigned footprints, cleaned some stuff up, fixed some ERC stuffs, imports schematic to pcb well, no errors other than the rotary encoder, gonna look into that real quick

oops didnt use the switch version

ok, thats fixed, updates well, some warnings but no errors, gonna look into that in a second but for now, quick commit! (yes i undid all the pcb stuff so that it actually updates when we do real stuff)

ok 10:37 PM, gonna go watch a movie now, brb!

back at 1:23 AM, let's quickly fix it, idk why my shoulders hurt a bunch today...

ok, looked in a bit deeper, shouldnt be an issue! hmm thinking about layout and we probably should break up all the gpio 20 pins into sections based on what they do for debug rather than in header form, since, well, it's not gonna be fun to route around them. yeah, probably will do that tomorrow... or why not now?

so uh, idk why the crystal size is off, gonna look into that tomorrow, but yeah, pin groups made!

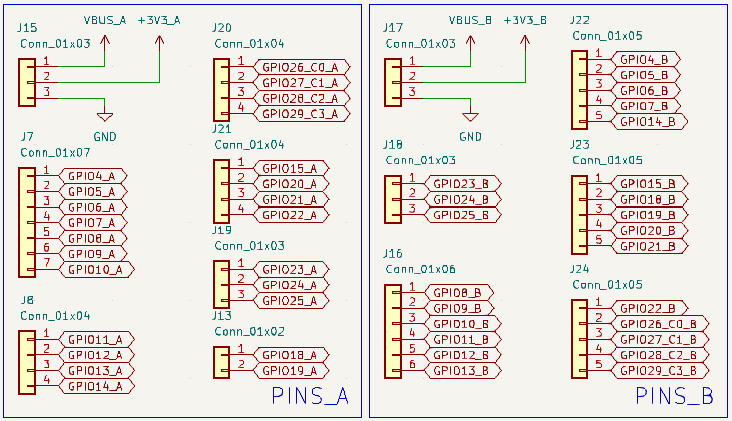
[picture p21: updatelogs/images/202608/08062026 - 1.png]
waw


the spi and uart and run pins have headers in the lower area for mcu communication (outside of the picture), so yeah, got a couple things to double check, but pcb work should be able to start soon!

and yeah! it's 2:27 AM, so that's about it for today, good night!

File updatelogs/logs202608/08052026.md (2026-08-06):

# 8/5/2026 - 9th Update!

yeah, took a day off yesterday for some silly art, anyways, 5:15 PM, and we're back!

ok, added the updatelog from 8/3/2026 onto the website, so we have to finish the schematic today!

todo
- update pins to add spi communication between the two mcus
- add backup for uart or some other communciation method
- add redundancy for other peripherals
    - other audio jack formats other than TRS, USB, etc.

and more lists

MCU A
- 0-3: SPI0 MCU (to implement)
- 0-6: Buttons (switch to 4-10)
    - updated, GPIO10 is the connector
- 8-11: Micro SD Card (switch to 11-14)
    - changed RX from 8 to 12
    - changed CS from 9 to 13
    - changed SCK from 10 to 14
- 12-13: OLED 128x32 Display (switch to 18-19)
    - changed SDA from 12 to 18
    - changed SCL from 13 to 19
- 16-17: UART0 MCU (backup) (to implement)
- 23-25: RGB, Board, Boot LEDS
- 26-28: Audio

MCU B
- 0-3: SPI0 MCU (to implement)
- 0-5: LCD 128x160 Display (switch to 8-13)
    - changed BLK, generic from 5 to 13
    - changed CS, SPI1 CSn from 1 to 9
    - changed DC, generic from 0 to 8
    - changed RST, generic from 4 to 12
    - changed SDA, SPI1 TX (MOSI) from 3 to 11
    - changed SCL, SPI1 SCK  from 2 to 10
- 16-17: UART0 MCU (backup) (to implement)
- 23-25: RGB, Board, Boot LEDS

ok, stuff updated, gotta implement the connection now, ok, pin set thingy added, also gotta consider how to do the board connection thing since it'll be more repairable if we have an array of pins headers instead of soldering the display directly to the board, but for now, quick commit!

so, in trying to rename a commit, i seem to have deleted the commit for 8/3/2026... uh, my bad

oh the timelines messed up a bit... uh, let's ignore that, 6:24 PM, off to dinner!

im back at 12:53 AM. no, dinner was not 6 hours lol

added a TS audio jack, then learned that, according to the [docs](https://pip-assets.raspberrypi.com/categories/814-rp2040/documents/RP-008279-DS-1-hardware-design-with-rp2040.pdf) under section 3.4, its not exactly for headphones but is meant for amplifier inputs (they do work with high impedance headphones but idk whether i have those)

huh kicad just went black

ok, back from kicad, just did a bunch of audio stuff, idk how much of its correct, but it's kinda 2:18 AM right now so yeah, here's a picture!

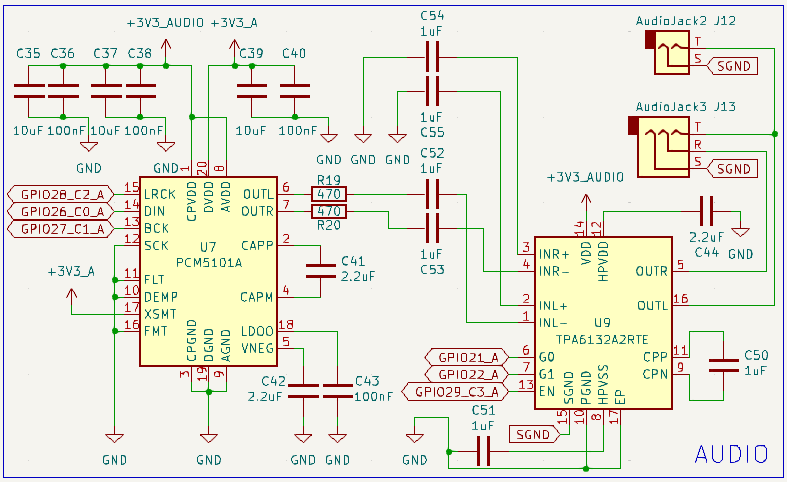
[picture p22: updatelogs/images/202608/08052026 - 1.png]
waw


yeah, had to mvoe things around a bit, idk, still gotta look more into this, had to pull up the datasheets lol (pull up? like pull up resistors???)

anyways, it's now 2:20 AM, so yeah, good night!

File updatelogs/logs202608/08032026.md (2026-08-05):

# 8/3/2026 - 8th Update!

9:20 PM, let's go

ok, figure 23 on page 25 of [this](https://pip-assets.raspberrypi.com/categories/814-rp2040/documents/RP-008279-DS-1-hardware-design-with-rp2040.pdf) raspberry pi documentation seems good, did a bit of research, seems that pcm is better than pwm here for audio use cases, with the tradeoff of requiring more electronics

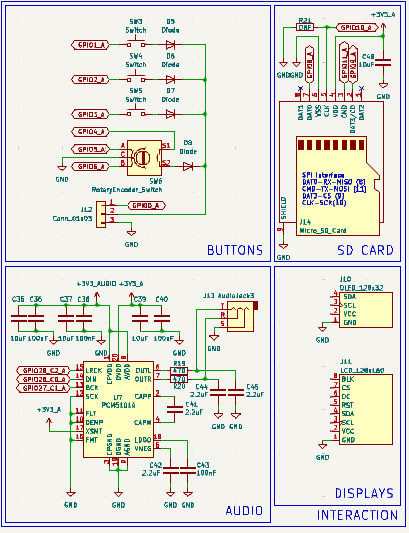
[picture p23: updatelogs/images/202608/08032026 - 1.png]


ok, so its like 11:16 PM, here's the progess! audio thing and sd card thing should both be done, need to look into how to program them (and to verify that its correct), but seems nice so far! still need to work on the display stuff, might also add some leds, quick commit!

ok, back at 11:57 PM (as in, i took a bit of a break), time to do the display and leds (maybe? idk)

ok, everythings looking good! still need to check if the spi for the displays are correct, but now we also need to consider how we're gonna do the communication between the rp2040s! 1:03 AM, gonna take a second to rest, quick commit!

ok, its a bit later now, i think im gonna end today here, decent progress, really need to finish the schematic and start layout tomorrow!

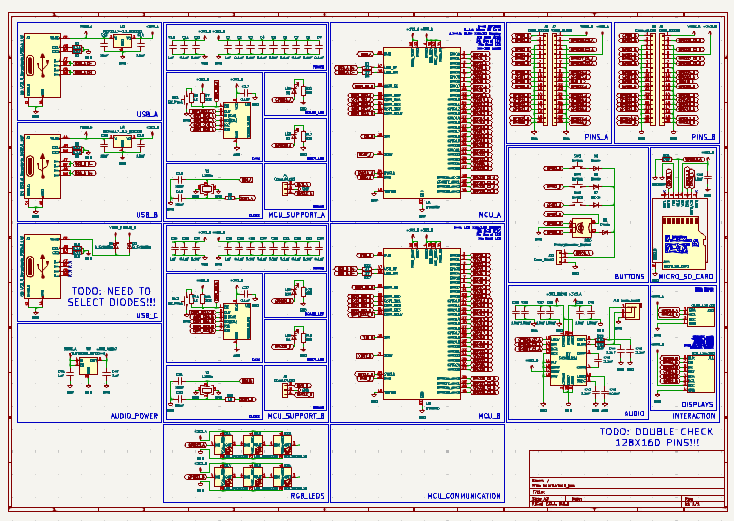
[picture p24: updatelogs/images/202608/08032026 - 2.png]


yeah! that said, it's 1:48 AM, so good night!

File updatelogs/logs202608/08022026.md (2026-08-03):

# 8/2/2026 - 7th Update!

3:56 PM, goal for today is to finish the schematic, verify it, then start work on the pcb itself! looking forward to that, seld reminder to double check what should be close with what and trace width too

welcome back! its actually 4:22 PM, i am not locked in

mfw i learn that you can flip components in schematic

ok, back at 5:35 PM! good progress, just placed a bunch of the out pins, of course, we're not exactly gonna use them, but it would be cool to actually just use them as a devboard as well! anyways, quick commit!

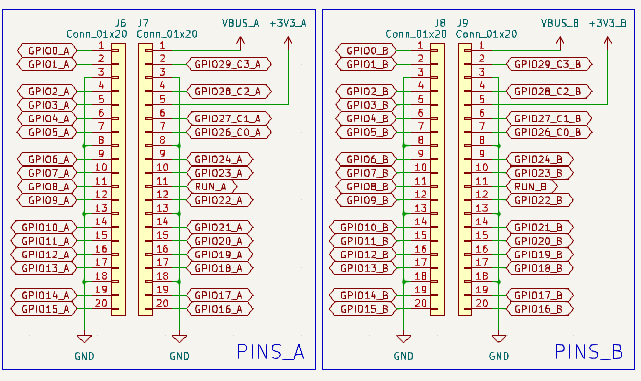
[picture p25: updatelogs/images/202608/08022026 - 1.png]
hmm


ok, 5:41 PM, brb! (bro is not coming back for a bit)

ok, 9:50 PM, im back! back to kicad... 

idk what im doing, made a footprint though!

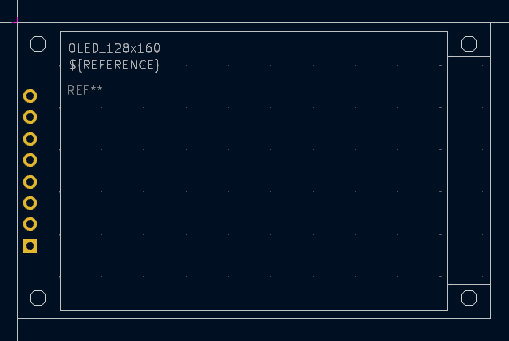
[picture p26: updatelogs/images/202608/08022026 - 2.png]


ok, added the stuff, assigned a bunch footprints to stuff, hmm still gotta wire the stuff

back at 11:40 PM, added the 128x160 display footprint and symbol, along with the switches and encoder wiring! gonna need a jumper thing there, probably should implement them more? idk

also, one more thing, i forgot. yeah, oh right, we need an audio jack thing (or some speaker? idk, research time)

quick commit!

ok, 1:17 AM, yeah, didnt get much done between then and now, didnt really feel exactly motivated to get back to it? anyways, idk how, but my short video on the capacitor text flying off screen has amassed 400+ likes and 8.8k+ views in 10 hours (which is like x20+ the amount of views the spark edit had, which took 5 hours lol), not complaining though!

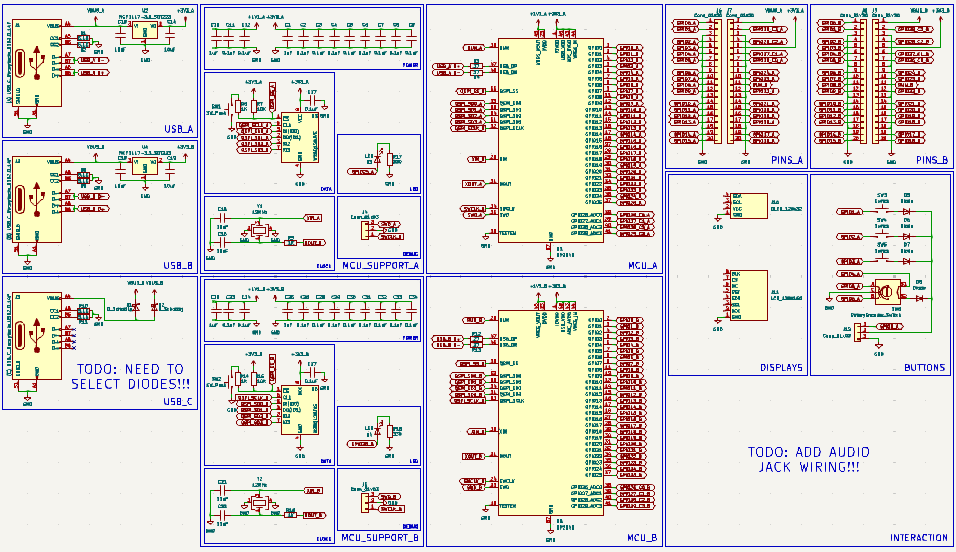
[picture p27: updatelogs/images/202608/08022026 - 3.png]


so yeah! that's the progress on the schematic so far, good amount of assigning footprints too! anyways, at the time of writing, it now has 9k+ views. which is kinda insane. anyways, yeah!

so, that's it for now, it's 1:24 AM, good night!

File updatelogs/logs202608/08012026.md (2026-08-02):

# 8/1/2026 - 6th Update!

its 5:26 PM, time to lock in, new month by the way! just moved yesterdays log onto the website

i dont think i can design it to have the top of the screws flush with the surface, idk, it might look better without that? who knows

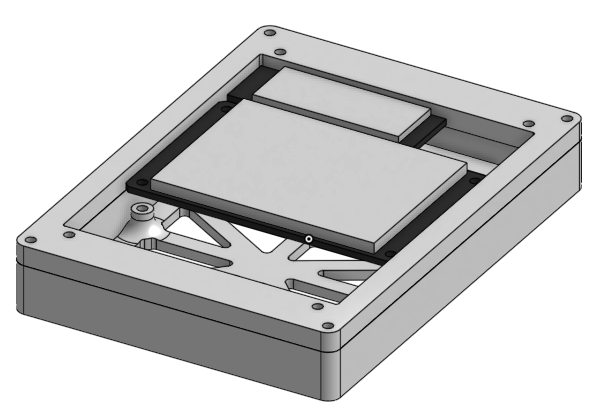
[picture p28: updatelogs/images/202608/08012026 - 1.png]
hmm


cad work is pretty good! time to move the work to kicad... (also, do note that the main screens gonna have some stuff so it can actually align well, we still have spacers and tabs to cad!) the main point of getting the case and layout

ok, 6:56 PM, made the kicad, gonna get started after dinner! quick commit

ok, 8:56 PM now, wow, basically exactly two hours later! no, i didnt eat dinner for two whole hours (yes ill keep making this joke)

anyways, pcb time, seems like theres no dedicated kicad wakatime/hackatime thing, thats kinda sad (im also on kicad 8 lel)

just checked the stardance site, why does my updatelog from yesterday have more views/reactions than any of the posts in spark lol

i have no clue where to start. probably gonna heavily reference [this](https://blueprint.hackclub.com/starter-projects/devboard) guide back from blueprint for resources! well, what am i waiting for? here we go! once i get lookout/timelapse thing set up!

ok, 10:14 PM, lots of stuff done! basically, im up to adding the io stuffs, but since we're not making a devboard (im still gonna break out a good amount of pins), we're just gonna gloss over that...

waw

anyways, yeah, quick commit!

so uh, ive been thinking. how does one power/program this. well, the idea right now is three usb c ports, one for only power and controlling everything, and the other two for individual power/flash! its a little jank, but idk how the power stuff is gonna work (at least for the capacitors)

we also need diodes aaaaaaa

ok, 10:45 PM, gonna go watch a movie, brb!

back at 1:39 AM, why am i scared to make changes, i have version control...

mfw there are 67 footprints in total (according to the assign footprints list), anyways, 2:37 AM, with that, i think here's a good place to stop for today, discovered the blue boxes existed and had a ton of fun with it!

waw

so yeah, that's it for tonight, it's currently 2:40 AM, good night!

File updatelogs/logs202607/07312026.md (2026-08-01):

# 7/31/2026 - 5th Update!

well, it's 9:41 PM, on the last day of july. quite a month lol

anyways, gotta lock in, back to cad!!!

since when were headers (long side, past the black square section) 6mm? guess they always were

we should also probably have a simple oled on the top for the text, with the graphics beneath it... it could probably be driven by the main rp2040 since its not that intensive

hmm might be better to put this on the second? idk, i dont think im gonna add a scrub bar (as in saying the progress of the track) in order to save processing power, i actually dont know, it might be a good idea actually

ok, some ui drawing later, we have a 128x32 image! probably not gonna actually put an image on the disc place, shouldnt take much effort for anything to update it (since its both monochrome and only 128x32) (maybe we can do some optimization to only update section of it if that's possible? idk)

[this](https://www.aliexpress.us/item/3256808453793642.html) looks pretty good, time to cad the picture! nvm, it doesnt have the pin locations in the picture...

[this](https://www.aliexpress.us/item/3256808732385444.html) is also pretty good, this time with the pin locations in the diagram! wait it doesnt have the side profile

mfw these are like the exact same products, just gonna go with the first one

erm this things gonna be 1.5cm tall in total, at least currently, thats pretty compact!

self reminder to add extra clearance on the sides of the display

ok, 10:42 PM, movie time, brb

back at 2:05 AM, so the layout of this things gonna have to be super super super annoying, gonna draw something out real quick, actually its probably faster to write it, basically, the base is obvious, just pla, but after that, we're gonna need some form of four screws to hold everything together, with spacers in between!

mentioned yesterday, with the ideas of the buttons on the side, it's still possible, but i'd say unlikely. it's not exactly easy to make easy push buttons on the side, we'll probably have to have some mount, which is also not pleasant to make, especially with the fact we have to wire that up. i'd more prefer if we could have it on the board itself, but that's obviouslly not possible

or is it?

turns out, while write that, i remembered that, since the height's 1.5cm, we can, in fact, have a couple of switches on the bottom! like, actual buttons!

we cant really fit full keyswitches there... well, we can fit three, and have the rotary encoder on the top

we might be onto something, speakers are gonna have to wait, probably unlikely, headphone jack is gonna be on the side, probably next to the power section

back to cad work

so i just researched 18650 batteries again. probably best to just use a charger. idk, still like the jumper for usb c and battery power idea

erm hows it 2:43 AM, ok, did a bit more cad work, here's the state of stuff

hmm

yeah, that's gonna be it for now, i should probably design this with more space, the x direction right now is set by the display itself, which is quite interesting, gonna probably have to make a protection thing so stuff doesnt collide, havent considered if i actually am gonna add a battery to it and exactly where (would need to find a battery holding unit and get the dimensions, probably gonna quickly grab that from the 18650 battery holders from `raven` or something)

anyways, 2:47 AM right now here in NYC, good night!

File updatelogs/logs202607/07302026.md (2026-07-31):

# 7/30/2026 - 4th Update!

welcome back

its 10:00 PM here in NYC, i really need to get my life together again, more research!

bros back to researching and sourcing

why does the "spi" module have sda and scl and no mosi or miso pins

ok, looking deeper into the datasheet of [this](https://www.aliexpress.us/item/2255800856040698.html) thing, the 2.4 inch display has a mosi pin, and the other ones also technically do too, but the description is just... misnamed? however, it needs an sd card (???)

so, for the 1.77 inch (though it says 2.0???)
- scl is the clock
- sda is the mosi
- cs is cs (chip select)
- dc is dc (data command)

huh it uses st7789 and idk about this

- [aliexpress](https://www.aliexpress.us/item/3256803610964639.html)
    - mfw no docs on pins
- [aliexpress](https://www.aliexpress.us/item/3256805953674718.html)
    - also good, but no docs or pins, so eh
- [aliexpress](https://www.aliexpress.us/item/3256808314273968.html)
    - some dimensions mentioned, eh pinout

some internet issues later, idk if just doing the 2.0 screen would be the move? it is x3.75 more pixels (240x320)

pico test time, yeah id probably be better to have 160x128

hold on [this](https://www.aliexpress.us/item/3256807859088652.html) looks pretty decent

hmm

hmm life selection? intriguing, yeah probably gonna do 1.8 inches for that! ok, gonna take a break for a second and then start speed cad! 11:33 PM right now, brb

ok, back at 12:04 AM, switched from summer reading audiobook to music, here we go!!!

yeah, probably best to get the 1.8 inches one since it seems to require the least weird setup?

should probably use female headers for the pins

anyways, my idea for the layout is gonna be the top screen, the pins, then the female connection, and the board on the bottom, letting the middle space also be usable for buttons on the top and bottom! speaker locations would also probably be on the sides, connectors probably on the bottom for ease, but middle if i have to (probably more convinient actually). also, yeah, probably no battery for this one! speakers on the back might also be necessary, but the obvious issue with that is, well, that defeats the purpose (as it just blasts music out the back)

yay

display cadded!

ok, 12:55 AM, gonna go to bed now! good night!

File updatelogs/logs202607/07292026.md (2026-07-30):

# 7/29/2026 - 3rd Update!

not sure if you caught yesterday's log in spark, but yeah, basically wrote an update to wrap everything up. kinda a sad ending, but hey, we know what's next now! after river we're gonna head to fermion for the real challenge

im still trying to fight some form of post con depression (the convention being outpost/open sauce), im ok, it's just that i dont feel much motivation to create anything right now. it might also just be because i put this in the way

so, what we waiting for? 6:48 PM in nyc and a time limit to beat, let's go! oh my s key fell out again

ok, was cleaning up my tabs for a second, back at 7:01 PM, wait we should probably do parts searching instead of that first

ok, doing a couple tests with a display i have right now, kinda hard to describe it, but heres the points

- at least for a 128x64 running on SCL/SDA, frequency for the xiao can be set to 1000*1000 (1 MHz?)
- its not perfect (when the frames update it seems to be divided down the middle, making it look like 128x32 and 128x32 areas)
- why does this happen? idk
- however, it seems to run 30FPS+ well, with the frames pregenerated and ignoring the "split" in the screen

it's also important to note that we cant use this display since we want the screen to appear continous (soldering nightmare)

ok, brb, dinner time, currently 7:31 PM, keep getting distracted aaa

back at 9:30 PM, after a bit of research, instead of using an SSD1306 OLED setup, it might be better to use an SPI TFT display (ST7735)

parts searching time

so uh, a little issue. turns out, 32x32 is like the best that it can do in RGB color, 64x64 for black and white (for both gradient and for monochrome)

that's not good. (this was tested on a raspberry pi pico with an rp2040)

good news, while the pico cant run well drawing every pixel, it seems to be able to draw 100 lines pretty fast. not the best, but we can work with that

10:14 PM, brb

back at 12:54 AM, yeah, might just have to switch to c, time to watch a tutorial?

hmm

so, you probably wont believe this, but in the c version, its running through every pixel of the display and putting a random number, and the led is barely flickering. like, it's going through every pixel right now. thats insane! (barely flickering as in, it's blinking really really fast)

ok, after shoving a couple calculations there, it slows down quite a bit

> put_pixel(i, ie, ((int) sin(i*ie+1155.0/2265/ie)) % 256);

yeah, seems to just be sin(), now it's blinking rather quickly, not as fast but still faster than python

im doing a bunch of work off camera, but thats to a xiao rp2040 i had laying around (thanks outpost), the same code worked! nice!

ok, so that gives a bit more confidence in me that it might be fine, today's mostly just a benchmark and stats day, hopefully we get more parts down tomorrow?

well, 1:56 AM now, should probably start updating the journal stuff on the website, good night!

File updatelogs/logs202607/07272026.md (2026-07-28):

# 7/27/2026 - 2nd Update!

ok, after today and watching one too many videos about the rp2040 and how to debug, i think im ready? to at least start, of course. for now, i think im gonna do this as my order of stuff:

- wants/scope
- find parts and limits
- case design
- pcb design
- programming aaa
- ship

not exactly the hardest thing to do. anyways, that said, we still got a bunch of work to do! ok, imma just define the scope, it's 10:26 PM, lemme make a project real quick, ok, done! this time isnt gonna count any time that ive spent watching help videos (from today and before), probably shouldve recorded that but its whatever

anyways, scope!

wants:
- compact, device-like form factor
- two (or more? depends on pixel count) displays slapped together for >30hz graphics
- use two microcontrollers (one for front, one for display processing)
    - probably gonna be two rp2040s
    - also, yes, the chip itself instead of using a board like the XIAO RP2040
- have buttons for a decent interface
    - four should be enough? (switch ui, back, pause, forward) (switch ui, left/negative, select, right/positive)
        - idk how volume and stuff at the same time, maybe a slider/potentiometer (what)
            - rotary encoder eyyyyy
    - six buttons is alright lol (idk)
- custom pcb rahhhhh
    - basically a custom dual dedicated devboard. of sorts.
- built in speakers and/or an earbud/aux jack
- usb c and definitely an sd card slot

maybe:
- bluetooth??? (i dont want to deal with esp32s)
    - would be cool, idk how to do it/if i want to deal with esp32s and however power them
    - or the thing that starts with an n i forgor
- battery powered???
    - would be convient, probably just gonna set as a future feature and just use usb power for now (i mean, just set up two pins and a voltage thingy along with a jumper)

wrote a quick readme while writing that! the goal is to finish this in like a week or less and spend the majority of august working on **?????** (no it still doesnt have a name...) anyways, i think thats a pretty decent scope!

well, 10:55 PM, gonna go watch a movie!

ok, 1:31 AM and im back, here we go, thinking about the UI right now

- playing screen (shows tracks and graphics)
    - (track back) (pause/play) (track forward)
    - (audio down) (return menu) (audio up)

do you really need any more buttons? i mean, other than a power switch, is anything else really necessary? i mean, it's just a music player. maybe settings or something but like, a 2x3 is great enough, i mean, if anything

- menu screen
    - (none) (none) (none)
    - (left) (choose) (right)

- settings
    - (up) (toggle) (none)
    - (down) (return menu) (none)

but you can kinda just access that by long presses or something? idk, theres definitely ways to optimize this. also, was originally thinking about keyswitches for this, but yeah, those are way too big for this purpose, gonna look into scissor/butterfly switches, nvm, theres no way to get these i guess

- layout
    - (pause/play) (audio volume (rotary encoder))
    - (track back) (track forward)
- long press actions
    - long press encoder itself to seek through the entire list with the audio volume
        - the encoder needs to also be a button!
    - long press play to switch to settings
        - encoder to seek
        - lower buttons to toggle/set state/change value

and that should be good? same features but a 2x2?

idk, it's 1:47 AM, for now, good night!

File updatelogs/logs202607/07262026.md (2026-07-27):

# 7/26/2026 - 1st Update!

well, it's quite... quiet here. i mean, it is a fresh new project after all... anyways, while we explore the stars with stardance, this stop's the first that shouldnt be very long!

basically, there's plans for **?????** and- hold on, why are they question marks? did this guy not decide on a name yet (spoiler: i havent decided on a name yet), but simply, the constraints of the project *might* require the need for a custom PCB. oh yeah, it's 1:49 AM on 7/27/2026 right now by the way. yeah. anyways, with my s key falling off the keyboard once more, here's the plan

river (gd reference hahahahaha) also fully enough fits with the purpose, of being a stepping stone for this upcoming future project that should be more advanced than spark (oh boy). idk if im gonna practice with more stuff in between, probably wont? you can probably guess what the next project is, but hey, im still working out the details (well, mostly just the name) of it!

anyways, where was i? oh right, it's just a custom pcb thats gonna use some strange components to basically be an overengineered music player. alongside preparing myself for any pcb work (i just speedran a macropad in half an hour, that's not exactly insanely complex stuff as on now), i also plan on trying to design it like a product, like something that's actually usuable in a nice form factor. this also can come somewhat helpful for **?????**, so hey, well time spent?

that's it for now, i might write up more details when im not busy while outside tomorrow, but yeah, expect things to come! hopefully! it's 1:55 AM, good night!

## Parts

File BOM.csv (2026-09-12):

Ordered | Part | Description | Source | Quantity | Price | Total | Link
FALSE | Board PCB | PCBA (Check PCBA Parts BOM!) | JLCPCB | NA (order) | $84.61 | $84.61
FALSE |  | Estimated Shipping (JLCPCB to NYC) | JLCPCB |  |  | $11.05
FALSE | Screws | M2 (16mm, 50pcs) | AliExpress | 1 | $1.41 | $1.41 | https://www.aliexpress.us/item/3256804341271555.html
FALSE | 128x32 OLED SSD1306 Display | Information Display (White, 1pc) | AliExpress | 1 | $2.44 | $2.44 | https://www.aliexpress.us/item/3256808453793642.html
FALSE | 128x160 TFT SPI Display | Graphics Display (1.8 inch TFT) | AliExpress | 1 | $4.06 | $4.06 | https://www.aliexpress.us/item/3256807859088652.html
FALSE | WS2812B LEDs | LEDs (Board Front) | Self | 3 | $0.00 | $0.00 | NA
FALSE | Micro SD Card | Any Micro SD Card | Self | 1 | $0.00 | $0.00 | NA
FALSE | EC11 Rotary Encoder | Rotary Encoder (Top) | Self | 1 | $0.00 | $0.00 | NA
FALSE | Cherry MX Switch | Lower 3 Buttons | Self | 3 | $0.00 | $0.00 | NA
FALSE | Buffer | Buffer for Price/Shipping |  |  |  | $5.00 | NA
 | TOTAL: |  |  |  |  | $108.57

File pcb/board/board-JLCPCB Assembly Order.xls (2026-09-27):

JLCPCB BOM Tool - BOM Matching
BOM name：board-JLCPCB Assembly Order.xlsx |  |  | Download Time：2026-09-27 07:28:19 |  |  |  | * Our matching results are updated in real-time, but stock and prices may change. If it's been over 24 hours, please re-match before placing your order.
PCB Assembled Qty：5 |  |  | Est. Total Price：29.5365
Your BOM |  |  |  | Matched Parts |  |  |  |  |  |  | Order Information
Designator | Comment | Footprint | JLCPCB Part # | Matches | Part # | Manufacturer | Footprint | Description | Category | Warning | JLCPCB Part # | Product link | Lib Type | Qty | Source | Total Price ($)
C13,C14,C19,C18 | 10uF | C_0603_1608Metric |  | Select by Customer | CL10A106KP8NNNC | Samsung Electro-Mechanics | 0603 | 10V 10uF X5R ±10% 0603 Multilayer Ceramic Capacitors MLCC - SMD/SMT ROHS | Multilayer Ceramic Capacitors MLCC - SMD/SMT |  | C19702 | https://jlcpcb.com/partdetail/20411-CL10A106KP8NNNC/C19702 | Basic | 8 | 8 JLCPCB | 0.2552
C21,C15,C22,C16 | 33pF | C_0402_1005Metric |  | Select by Customer | 0402CG330J500NT | FH (Guangdong Fenghua Advanced Tech) | 0402 | 33pF 50V C0G ±5% 0402 Multilayer Ceramic Capacitors MLCC - SMD/SMT ROHS | Multilayer Ceramic Capacitors MLCC - SMD/SMT |  | C1562 | https://jlcpcb.com/partdetail/1914-0402CG330J500NT/C1562 | Basic | 8 | 8 JLCPCB | 0.0312
C25,C46,C51,C10,C49,C45,C1,C47,C20,C50 | 1uF | C_0402_1005Metric |  | Select by Customer | CL05A105KA5NQNC | Samsung Electro-Mechanics | 0402 | 1uF 25V X5R ±10% 0402 Multilayer Ceramic Capacitors MLCC - SMD/SMT ROHS | Multilayer Ceramic Capacitors MLCC - SMD/SMT |  | C52923 | https://jlcpcb.com/partdetail/53938-CL05A105KA5NQNC/C52923 | Basic | 20 | 20 JLCPCB | 0.198
C29,C32,C24,C26,C30,C3,C27,C12,C4,C2,C6,C7,C33,C11,C34,C31,C17,C9,C23,C28,C8,C5 | 0.1uF | C_0402_1005Metric |  | Select by Customer | CL05B104KO5NNNC | Samsung Electro-Mechanics | 0402 | 100nF 16V X7R ±10% 0402 Multilayer Ceramic Capacitors MLCC - SMD/SMT ROHS | Multilayer Ceramic Capacitors MLCC - SMD/SMT | 1.The comment (CL05B104KO5NNNC) of this part does not match the one (0.1uF) provided in your BOM. Please confirm; 2.Multiple lines in the BOM have been matched to the same part. Please check if the matching is correct. ; | C1525 | https://jlcpcb.com/partdetail/1877-CL05B104KO5NNNC/C1525 | Basic | 52 | 52 JLCPCB | 0.234
C36,C38,C40,C43 | 100nF | C_0402_1005Metric |  | Select by Customer | CL05B104KO5NNNC | Samsung Electro-Mechanics | 0402 | 100nF 16V X7R ±10% 0402 Multilayer Ceramic Capacitors MLCC - SMD/SMT ROHS | Multilayer Ceramic Capacitors MLCC - SMD/SMT | 1.Multiple lines in the BOM have been matched to the same part. Please check if the matching is correct. ; | C1525 | https://jlcpcb.com/partdetail/1877-CL05B104KO5NNNC/C1525 | Basic | 52 | 52 JLCPCB | 0.234
C39,C48,C35,C37 | 10uF | C_0402_1005Metric |  | Select by Customer | CL05A106MQ5NUNC | Samsung Electro-Mechanics | 0402 | 10uF 6.3V X5R ±20% 0402 Multilayer Ceramic Capacitors MLCC - SMD/SMT ROHS | Multilayer Ceramic Capacitors MLCC - SMD/SMT |  | C15525 | https://jlcpcb.com/partdetail/16204-CL05A106MQ5NUNC/C15525 | Basic | 8 | 8 JLCPCB | 0.204
C41,C52,C44,C42 | 2.2uF | C_0402_1005Metric |  | Select by Customer | CL05A225MQ5NSNC | Samsung Electro-Mechanics | 0402 | 2.2uF 6.3V X5R ±20% 0402 Multilayer Ceramic Capacitors MLCC - SMD/SMT ROHS | Multilayer Ceramic Capacitors MLCC - SMD/SMT |  | C12530 | https://jlcpcb.com/partdetail/13164-CL05A225MQ5NSNC/C12530 | Basic | 8 | 8 JLCPCB | 0.0424
D2,D1 | SS14 | D_SMA |  | Select by Customer | SS14 | MDD(Microdiode Semiconductor) | SMA(DO-214AC) | -55℃~+150℃ 1A 25A 300uA@40V 40V 550mV@1A Independent SMA(DO-214AC) Schottky Diodes ROHS | Schottky Diodes |  | C2480 | https://jlcpcb.com/partdetail/MDD_Microdiode_Semiconductor-SS14/C2480 | Basic | 4 | 4 JLCPCB | 0.0764
D5,D10,D3,D4,D9 | LED | LED_0603_1608Metric |  | Select by Customer | NCD0603Y2 | Foshan NationStar Optoelectronics | 0603 | -30℃~+85℃ 1.6V~2.6V 130° 220mcd 25mA 586nm~595nm 595nm 65mW Discrete Diode Yellow 0603 LED Indication - Discrete ROHS | LED Indication - Discrete | 1.The comment (NCD0603Y2) of this part does not match the one (LED) provided in your BOM. Please confirm; | C89811 | https://jlcpcb.com/partdetail/90993-NCD0603Y2/C89811 | Extended | 20 | 20 JLCPCB | 0.39
D12,D11,D13 | LED_WS2812B | LED_WS2812B |  | Select by Customer | DY-S505016/RGBC/6812F-NL-1T | TONYU | SMD5050-4P | -40℃~+80℃ 1.2kHz 1.6mm 100mcd~300mcd、100mcd~300mcd、900mcd~1200mcd 1mA 2000V 3.7V~5.5V 5.4mm 5mm 800Kbit/s R:620nm~625nm、G:520nm~530nm、B:460nm~470nm SMD5050-4P RGB LEDs(Built-in IC) ROHS | RGB LEDs(Built-In IC) |  | C524052 | https://jlcpcb.com/partdetail/TONYU-DY_S505016_RGBC_6812F_NL1T/C524052 | Extended | 8 | 8 JLCPCB | 0.9328
J1 | (A)USB_C_Receptacle_USB2.0_14P | USB_C_Receptacle_HRO_TYPE-C-31-M-12 |  | Select by Customer | TYPE-C-31-M-12 | Korean Hroparts Elec | SMD | -30℃~+80℃ 1 10,000 cycles 16P 20V 5A 7.35mm Female Surface Mount, Right Angle Type-C SMD USB Connectors ROHS | USB Connectors | 1.Multiple lines in the BOM have been matched to the same part. Please check if the matching is correct. ; | C165948 | https://jlcpcb.com/partdetail/Korean_HropartsElec-TYPE_C_31_M12/C165948 | Extended | 6 | 6 JLCPCB | 1.113
J2 | (B)USB_C_Receptacle_USB2.0_14P | USB_C_Receptacle_HRO_TYPE-C-31-M-12 |  | Select by Customer | TYPE-C-31-M-12 | Korean Hroparts Elec | SMD | -30℃~+80℃ 1 10,000 cycles 16P 20V 5A 7.35mm Female Surface Mount, Right Angle Type-C SMD USB Connectors ROHS | USB Connectors | 1.Multiple lines in the BOM have been matched to the same part. Please check if the matching is correct. ; | C165948 | https://jlcpcb.com/partdetail/Korean_HropartsElec-TYPE_C_31_M12/C165948 | Extended | 6 | 6 JLCPCB | 1.113
J3 | (C)USB_C_Receptacle_USB2.0_14P | USB_C_Receptacle_HRO_TYPE-C-31-M-12 |  | Select by Customer | TYPE-C-31-M-12 | Korean Hroparts Elec | SMD | -30℃~+80℃ 1 10,000 cycles 16P 20V 5A 7.35mm Female Surface Mount, Right Angle Type-C SMD USB Connectors ROHS | USB Connectors | 1.Multiple lines in the BOM have been matched to the same part. Please check if the matching is correct. ; | C165948 | https://jlcpcb.com/partdetail/Korean_HropartsElec-TYPE_C_31_M12/C165948 | Extended | 6 | 6 JLCPCB | 1.113
J12 | AudioJack3 | Jack_3.5mm_CUI_SJ-3523-SMT_Horizontal |  | Select by Customer | SJ-3523-SMT-TR | CUI | SMD | -25℃~+85℃ 12V 1A 3.5mm Headphone Jack Brass、Copper alloy Silver SMD Audio Connectors ROHS | Audio Connectors (Headphones) |  | C4991872 | https://jlcpcb.com/partdetail/CUI-SJ_3523_SMTTR/C4991872 | Extended | 2 | 2 JLCPCB | 2.5204
J14 | Micro_SD_Card | microSD_HC_Molex_47219-2001 |  | Select by Customer | 472192001 | MOLEX | SMD | -20℃~+85℃ 1.9mm Connector and Ejector Hinged Lid MicroSD Card (TF Card) No SMD SD Card / Memory Card Connector ROHS | SD Card / Memory Card Connector |  | C164170 | https://jlcpcb.com/partdetail/MOLEX-472192001/C164170 | Extended | 2 | 2 JLCPCB | 1.4422
R2,R9,R10,R8,R11,R1 | 5.1K | R_0402_1005Metric |  | Select by Customer | 0402WGF5101TCE | UNI-ROYAL(Uniroyal Elec) | 0402 | -55℃~+155℃ 5.1kΩ 50V 62.5mW Thick Film Resistor ±1% ±100ppm/℃ 0402 Chip Resistor - Surface Mount ROHS | Chip Resistor - Surface Mount |  | C25905 | https://jlcpcb.com/partdetail/26648-0402WGF5101TCE/C25905 | Basic | 12 | 12 JLCPCB | 0.0288
R4,R12,R13,R3 | 27 | R_0402_1005Metric |  | Select by Customer | 0402WGF270JTCE | UNI-ROYAL(Uniroyal Elec) | 0402 | -55℃~+155℃ 27Ω 50V 62.5mW Thick Film Resistor ±1% ±100ppm/℃ 0402 Chip Resistor - Surface Mount ROHS | Chip Resistor - Surface Mount | 1.The comment (0402WGF270JTCE) of this part does not match the one (27) provided in your BOM. Please confirm; | C25100 | https://jlcpcb.com/partdetail/25843-0402WGF270JTCE/C25100 | Extended | 20 | 20 JLCPCB | 0.038
R15,R7 | 10K | R_0402_1005Metric |  | Select by Customer | 0402WGF1002TCE | UNI-ROYAL(Uniroyal Elec) | 0402 | -55℃~+155℃ 10kΩ 50V 62.5mW Thick Film Resistor ±1% ±100ppm/℃ 0402 Chip Resistor - Surface Mount ROHS | Chip Resistor - Surface Mount | 1.The comment (0402WGF1002TCE) of this part does not match the one (10K) provided in your BOM. Please confirm; | C25744 | https://jlcpcb.com/partdetail/26487-0402WGF1002TCE/C25744 | Basic | 4 | 4 JLCPCB | 0.0136
R16,R5,R6,R14 | 1K | R_0402_1005Metric |  | Select by Customer | 0402WGF1001TCE | UNI-ROYAL(Uniroyal Elec) | 0402 | -55℃~+155℃ 1kΩ 50V 62.5mW Thick Film Resistor ±1% ±100ppm/℃ 0402 Chip Resistor - Surface Mount ROHS | Chip Resistor - Surface Mount | 1.The comment (0402WGF1001TCE) of this part does not match the one (1K) provided in your BOM. Please confirm; | C11702 | https://jlcpcb.com/partdetail/12256-0402WGF1001TCE/C11702 | Basic | 8 | 8 JLCPCB | 0.0144
R20,R19 | 470 | R_0402_1005Metric |  | Select by Customer | 0402WGF4700TCE | UNI-ROYAL(Uniroyal Elec) | 0402 | -55℃~+155℃ 470Ω 50V 62.5mW Thick Film Resistor ±1% ±100ppm/℃ 0402 Chip Resistor - Surface Mount ROHS | Chip Resistor - Surface Mount | 1.The comment (0402WGF4700TCE) of this part does not match the one (470) provided in your BOM. Please confirm; | C25117 | https://jlcpcb.com/partdetail/25860-0402WGF4700TCE/C25117 | Basic | 4 | 4 JLCPCB | 0.0108
R21 | DNF | R_0402_1005Metric |  | Select by Customer | 0402WGF1004TCE | UNI-ROYAL(Uniroyal Elec) | 0402 | -55℃~+155℃ 1MΩ 50V 62.5mW Thick Film Resistor ±1% ±100ppm/℃ 0402 Chip Resistor - Surface Mount ROHS | Chip Resistor - Surface Mount |  | C26083 | https://jlcpcb.com/partdetail/26826-0402WGF1004TCE/C26083 | Basic | 2 | 2 JLCPCB | 0.0052
R22,R24,R18,R26,R25,R23,R17 | 330 | R_0402_1005Metric |  | Select by Customer | 0402WGF3300TCE | UNI-ROYAL(Uniroyal Elec) | 0402 | -55℃~+155℃ 330Ω 50V 62.5mW Thick Film Resistor ±1% ±100ppm/℃ 0402 Chip Resistor - Surface Mount ROHS | Chip Resistor - Surface Mount | 1.The comment (0402WGF3300TCE) of this part does not match the one (330) provided in your BOM. Please confirm; | C25104 | https://jlcpcb.com/partdetail/25847-0402WGF3300TCE/C25104 | Basic | 14 | 14 JLCPCB | 0.056
SW1,SW2 | SW_Push | SW_Push_SPST_NO_Alps_SKRK |  | Select by Customer | TS-1088-AR02016 | XUNPU | SMD,4x3mm | -30℃~+80℃ 1.6N 100,000 cycles 12V 2mm 3.9mm 3mm 50mA Black Round Button SMD(SMT) Tab SPST Surface Mount,Vertical Without Bracket SMD,4x3mm Tactile Switches ROHS | Tactile Switches |  | C720477 | https://jlcpcb.com/partdetail/XUNPU-TS_1088AR02016/C720477 | Basic | 4 | 4 JLCPCB | 0.2144
U3,U6 | W25Q16JVZPIQTR | Winbond_USON-8-1EP_3x2mm_P0.5mm_EP0.2x1.6mm |  | Select by Customer | W25Q16JVUXIQ | Winbond Elec | USON-8-EP(2x3) | -40℃~+85℃ 100,000 cycles 10uA 133MHz 16Mbit 2.7V~3.6V 20 Years 3ms SPI USON-8-EP(2x3) NOR FLASH ROHS | NOR FLASH | 1.The comment (W25Q16JVUXIQ) of this part does not match the one (W25Q16JVZPIQTR) provided in your BOM. Please confirm; | C2843335 | https://jlcpcb.com/partdetail/WinbondElec-W25Q16JVUXIQ/C2843335 | Extended | 4 | 4 JLCPCB | 6.2944
U4,U2 | NCP1117-3.3_SOT223 | SOT-223-3_TabPin2 |  | Select by Customer | NCP1117ST33T3G | onsemi | SOT-223 | 0.003%Vout 0℃~+125℃@(Ta) 1 1.2V@(800mA) 1A 20V 3.3V 62dB@(120Hz) 6mA Fixed Over Current Protection、Thermal Shutdown Positive SOT-223 Voltage Regulators - Linear, Low Drop Out (LDO) Regulators ROHS | Voltage Regulators - Linear, Low Drop Out (LDO) Regulators |  | C26537 | https://jlcpcb.com/partdetail/onsemi-NCP1117ST33T3G/C26537 | Extended | 4 | 4 JLCPCB | 0.9272
U5,U1 | RP2040 | QFN-56-1EP_7x7mm_P0.4mm_EP3.2x3.2mm |  | Select by Customer | RP2040 | Raspberry Pi | LQFN-56(7x7) | 12bit 133MHz 30 LQFN-56(7x7) Microcontrollers (MCU/MPU/SOC) ROHS | Microcontrollers (MCU/MPU/SOC) |  | C2040 | https://jlcpcb.com/partdetail/RaspberryPi-RP2040/C2040 | Extended | 4 | 4 JLCPCB | 3.9496
U7 | PCM5101A | TSSOP-20_4.4x6.5mm_P0.65mm |  | Select by Customer | PCM5101APW | Texas Instruments | TSSOP-20 | -25℃~+85℃ 1.8V~3.6V 2 32 I2S TSSOP-20 ADCs/DACs - Special Purpose ROHS | ADCs/DACs - Special Purpose | 1.The comment (PCM5101APW) of this part does not match the one (PCM5101A) provided in your BOM. Please confirm; | C1540128 | https://jlcpcb.com/partdetail/TexasInstruments-PCM5101APW/C1540128 | Extended | 2 | 2 JLCPCB | 4.047
U8 | TLV70033_SOT23-5 | SOT-23-5 |  | Select by Customer | TLV70033DDCR | Texas Instruments | SOT-23-5 | -40℃~+125℃@(Tj) 1 200mA 3.3V 31uA 48uVrms 5.5V 68dB Fixed Over Current Protection Positive SOT-23-5 Voltage Regulators - Linear, Low Drop Out (LDO) Regulators ROHS | Voltage Regulators - Linear, Low Drop Out (LDO) Regulators |  | C11337 | https://jlcpcb.com/partdetail/TexasInstruments-TLV70033DDCR/C11337 | Extended | 5 | 5 JLCPCB | 0.8395
U9 | TPA6132A2RTE | WQFN-16-1EP_3x3mm_P0.5mm_EP1.6x1.6mm_ThermalVias |  | Select by Customer | TPA6132A2RTER | Texas Instruments | WQFN-16-EP(3x3) | -40℃~+85℃ 0.01% 100dB 100dB 2-Channel 2.1mA 2.3V~5.5V 25mWx2@16Ω Automatic mute/no-noise switch、Enable/shutdown function、ESD protection、Digitally programmable gain Class AB WQFN-16-EP(3x3) Audio Amplifiers ROHS | Audio Amplifiers | 1.The comment (TPA6132A2RTER) of this part does not match the one (TPA6132A2RTE) provided in your BOM. Please confirm; | C69901 | https://jlcpcb.com/partdetail/TexasInstruments-TPA6132A2RTER/C69901 | Extended | 2 | 2 JLCPCB | 2.8192
Y2,Y1 | 12MHz | Crystal_SMD_3225-4Pin_3.2x2.5mm |  | Select by Customer | X322512MSB4SI | YXC Crystal Oscillators | SMD3225-4P | -40℃~+85℃ 12MHz 20pF 80Ω Crystal Oscillator ±10ppm ±20ppm SMD3225-4P Crystals ROHS | Crystals |  | C9002 | https://jlcpcb.com/partdetail/YXC_CrystalOscillators-X322512MSB4SI/C9002 | Basic | 4 | 4 JLCPCB | 0.3788

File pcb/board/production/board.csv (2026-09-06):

Id | Designator | Footprint | Quantity | Comment | Supplier and ref
1 | J8,J16,J15 | PinHeader_1x01_P2.54mm_Vertical | 3 | Conn_01x01
2 | SW6 | RotaryEncoder_Alps_EC11E-Switch_Vertical_H20mm | 1 | RotaryEncoder_Switch
3 | SW3,SW4,SW5 | SW_Cherry_MX_1.00u_PCB | 3 | Switch
4 | J9,J6,J18,J19,J17,J22,J21,J20 | TestPoint_Pad_D1.0mm | 8 | Conn_01x01
5 | J13,J7 | TestPoint_Pad_1.0x1.0mm | 2 | Conn_01x01
6 | D15,D14,D16,D12,D11,D13 | LED_WS2812B | 6 | LED_WS2812B
7 | J11 | LCD_128x160 | 1 | LCD_128x160
8 | J10 | OLED_128x32 | 1 | OLED_128x32
9 | SW1,SW2 | SW_Push_SPST_NO_Alps_SKRK | 2 | SW_Push
10 | C29,C32,C24,C26,C30,C3,C27,C12,C4,C2,C6,C7,C33,C11,C34,C31,C17,C9,C23,C28,C8,C5 | C_0402_1005Metric | 22 | 0.1uF
11 | R22,R24,R18,R26,R25,R23,R17 | R_0402_1005Metric | 7 | 330
12 | D5,D10,D3,D4,D9 | LED_0603_1608Metric | 5 | LED
13 | C39,C48,C35,C37 | C_0402_1005Metric | 4 | 10uF
14 | C21,C15,C22,C16 | C_0402_1005Metric | 4 | 33pF
15 | U4,U2 | SOT-223-3_TabPin2 | 2 | NCP1117-3.3_SOT223
16 | R15,R7 | R_0402_1005Metric | 2 | 10K
17 | D2,D1 | D_SMA | 2 | SS14
18 | R2,R9,R10,R8,R11,R1 | R_0402_1005Metric | 6 | 5.1K
19 | U3,U6 | Winbond_USON-8-1EP_3x2mm_P0.5mm_EP0.2x1.6mm | 2 | W25Q16JVZPIQ TR
20 | C25,C46,C51,C10,C49,C45,C1,C47,C20,C50 | C_0402_1005Metric | 10 | 1uF
21 | J3 | USB_C_Receptacle_HRO_TYPE-C-31-M-12 | 1 | (C) USB_C_Receptacle_USB2.0_14P
22 | R4,R12,R13,R3 | R_0402_1005Metric | 4 | 27
23 | U9 | WQFN-16-1EP_3x3mm_P0.5mm_EP1.6x1.6mm_ThermalVias | 1 | TPA6132A2RTE
24 | R20,R19 | R_0402_1005Metric | 2 | 470
25 | C41,C52,C44,C42 | C_0402_1005Metric | 4 | 2.2uF
26 | R21 | R_0402_1005Metric | 1 | DNF
27 | C36,C38,C40,C43 | C_0402_1005Metric | 4 | 100nF
28 | J12 | Jack_3.5mm_CUI_SJ-3523-SMT_Horizontal | 1 | AudioJack3
29 | U7 | TSSOP-20_4.4x6.5mm_P0.65mm | 1 | PCM5101A
30 | J1 | USB_C_Receptacle_HRO_TYPE-C-31-M-12 | 1 | (A) USB_C_Receptacle_USB2.0_14P
31 | U5,U1 | QFN-56-1EP_7x7mm_P0.4mm_EP3.2x3.2mm | 2 | RP2040
32 | R16,R5,R6,R14 | R_0402_1005Metric | 4 | 1K
33 | J2 | USB_C_Receptacle_HRO_TYPE-C-31-M-12 | 1 | (B) USB_C_Receptacle_USB2.0_14P
34 | U8 | SOT-23-5 | 1 | TLV70033_SOT23-5
35 | C13,C14,C19,C18 | C_0603_1608Metric | 4 | 10uF
36 | Y2,Y1 | Crystal_SMD_3225-4Pin_3.2x2.5mm | 2 | 12MHz
37 | J14 | microSD_HC_Molex_47219-2001 | 1 | Micro_SD_Card

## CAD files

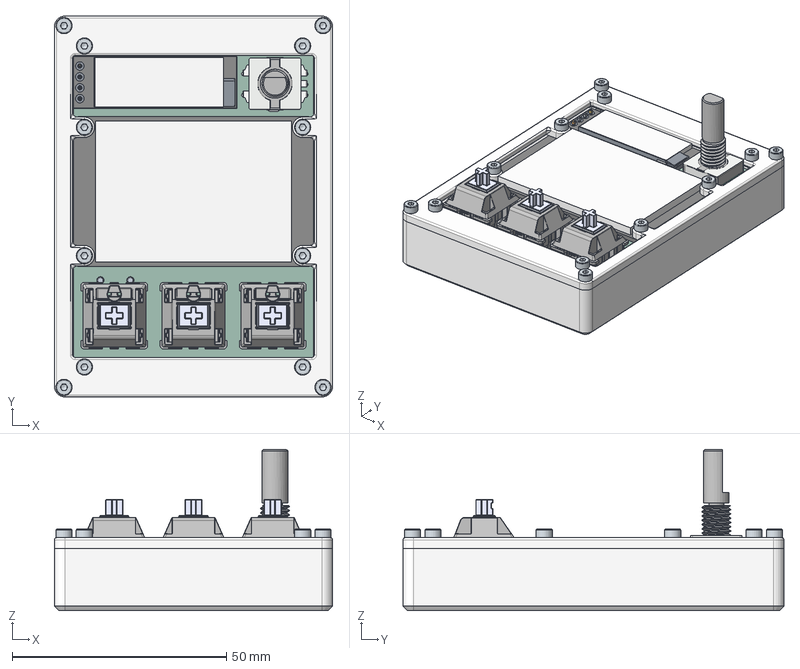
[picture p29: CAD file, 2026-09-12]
cad/river-Full Assembly-2026-09-11 23-05-53.step
65.0 x 89.0 x 37.6 mm
Hex socket head cap screw M2x0.40 x 16 x 12
upper case
lower case
MX Öá °´¼ü¡ä_¨¹ ___¡§1:1__Body1 x 3
MX Öá ÖáÌå¨¢¨¬ _¡§¡é¡§__:1__Body1 x 3
MXÖá ÖáÌå µ×²¿ ¦Ì¡ Á2__Ä¬ÈÏ_¨¢2____¨¨_:1__Body1 x 3
Õë½Å___Ä¬ÈÏ__¨¨ _:1__Body1 x 3
Õë½Å___Ä¬ÈÏ__¨¨ _:1__Body2 x 3
Imported1 x 21
EC11 v3:1__Body5
EC11 v3:1__Body2
EC11 v3:1__Body4
EC11 v3:1__Body1
EC11 v3:1__Body3
EC11 v3:1__Body6
display 128x160
display 128x32
OLED_0.91_128x32 x 52
R_0402_1005Metric_12
SOT_223
Crystal_SMD_3225-4Pin_3.2x2.5mm_1
C_0402_1005Metric_34
C_0402_1005Metric_37
LED_WS2812B_PLCC4_50x50mm_P32mm_2
C_0402_1005Metric_29
D_SMA
C_0402_1005Metric_26
TSSOP_20_44x65mm_P065mm
LED_WS2812B_PLCC4_50x50mm_P32mm_3
C_0402_1005Metric_20
R_0402_1005Metric
C_0402_1005Metric_6
C_0402_1005Metric_16
C_0402_1005Metric_1
Crystal_SMD_3225-4Pin_3.2x2.5mm
C_0402_1005Metric_5
R_0402_1005Metric_15
LED_WS2812B_PLCC4_50x50mm_P32mm_4
R_0402_1005Metric_22
C_0603_1608Metric
R_0402_1005Metric_6
R_0402_1005Metric_7
C_0402_1005Metric_33
R_0402_1005Metric_10
C_0402_1005Metric_22
C_0402_1005Metric_41
R_0402_1005Metric_4
C_0603_1608Metric_1
R_0402_1005Metric_24
C_0402_1005Metric_24
R_0402_1005Metric_21
C_0402_1005Metric_18
R_0402_1005Metric_3
D_SMA_1
R_0402_1005Metric_9
C_0402_1005Metric_17
C_0402_1005Metric_25
C_0402_1005Metric_44
C_0402_1005Metric_31
C_0402_1005Metric_21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

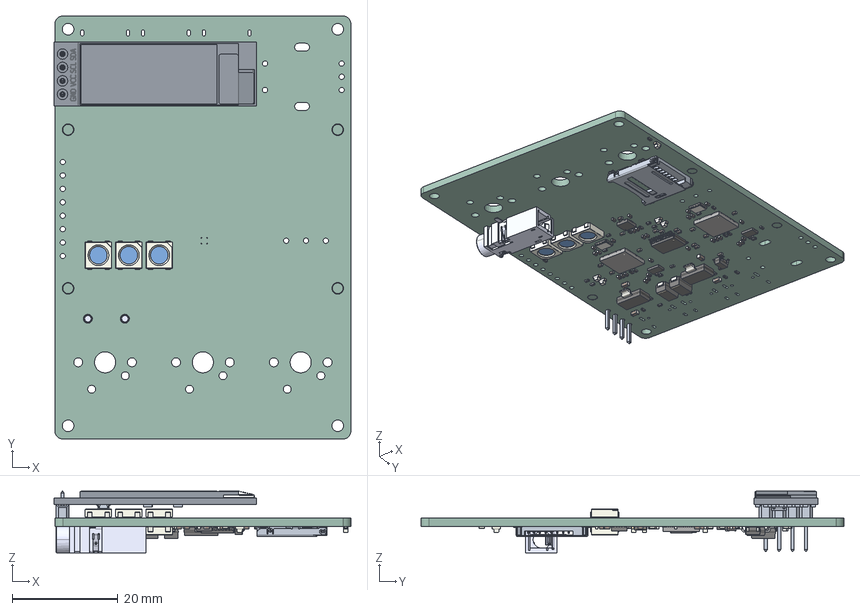
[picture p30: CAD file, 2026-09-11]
pcb/board/board.step
56.1 x 80.0 x 11.7 mm
LED_WS2812B_PLCC4_50x50mm_P32mm x 6
OLED_0.91_128x32
C_0402_1005Metric x 48
R_0402_1005Metric x 26
LED_0603_1608Metric x 5
SOT_223 x 2
D_SMA x 2
Winbond_USON-8-1EP_3x2mm_P0.5mm_EP0.2x1.6mm x 2
WQFN_16_1EP_3x3mm_P05mm_EP16x16mm
CUI_DEVICES_SJ-3523-SMT-TR
TSSOP_20_44x65mm_P065mm
QFN_56_1EP_7x7mm_P04mm_EP32x32mm x 2
SOT_23_5
C_0603_1608Metric x 4
Crystal_SMD_3225-4Pin_3.2x2.5mm x 2
board_PCB_1
board_PCB_2
board_PCB_3
board_PCB_4
board_PCB_5

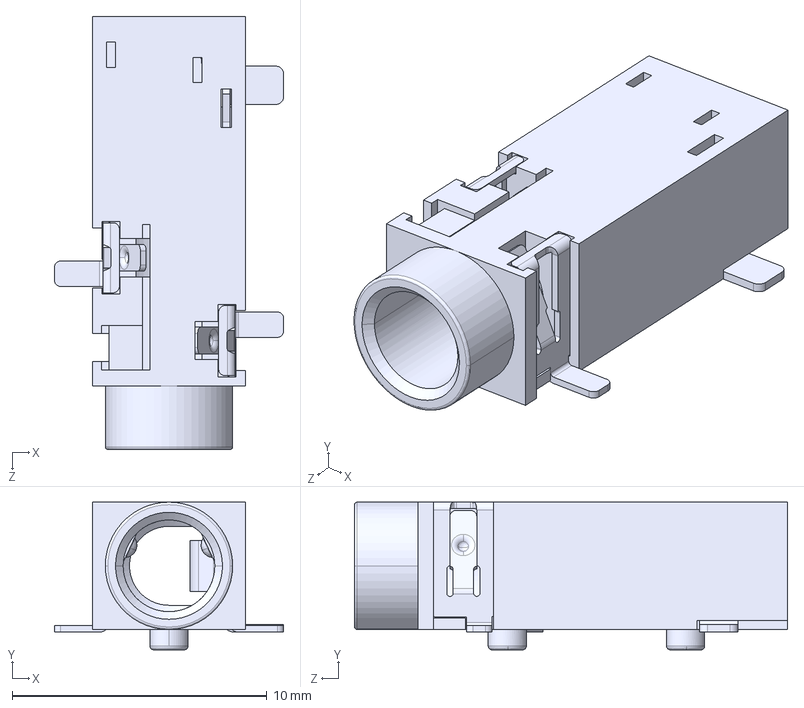
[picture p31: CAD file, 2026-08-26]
pcb/board/Same_Sky_SJ-3523-SMT-TR.step
9.00 x 5.80 x 17.0 mm

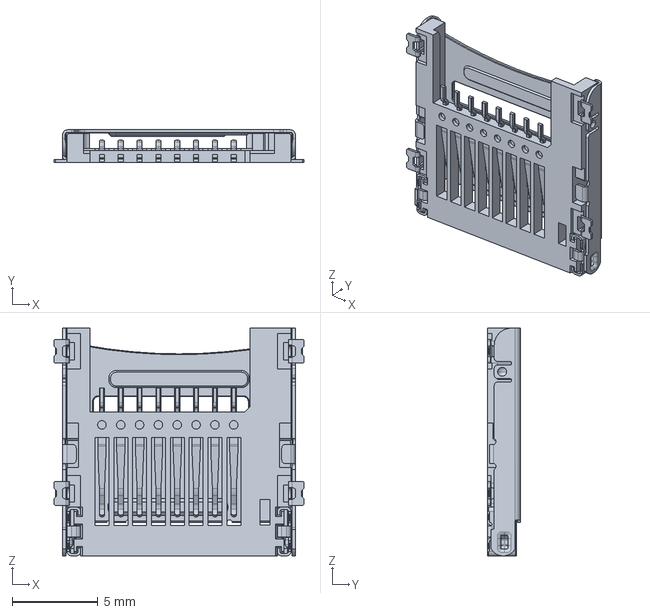
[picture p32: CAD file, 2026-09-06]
pcb/board/472192001.stp
14.6 x 1.90 x 13.3 mm

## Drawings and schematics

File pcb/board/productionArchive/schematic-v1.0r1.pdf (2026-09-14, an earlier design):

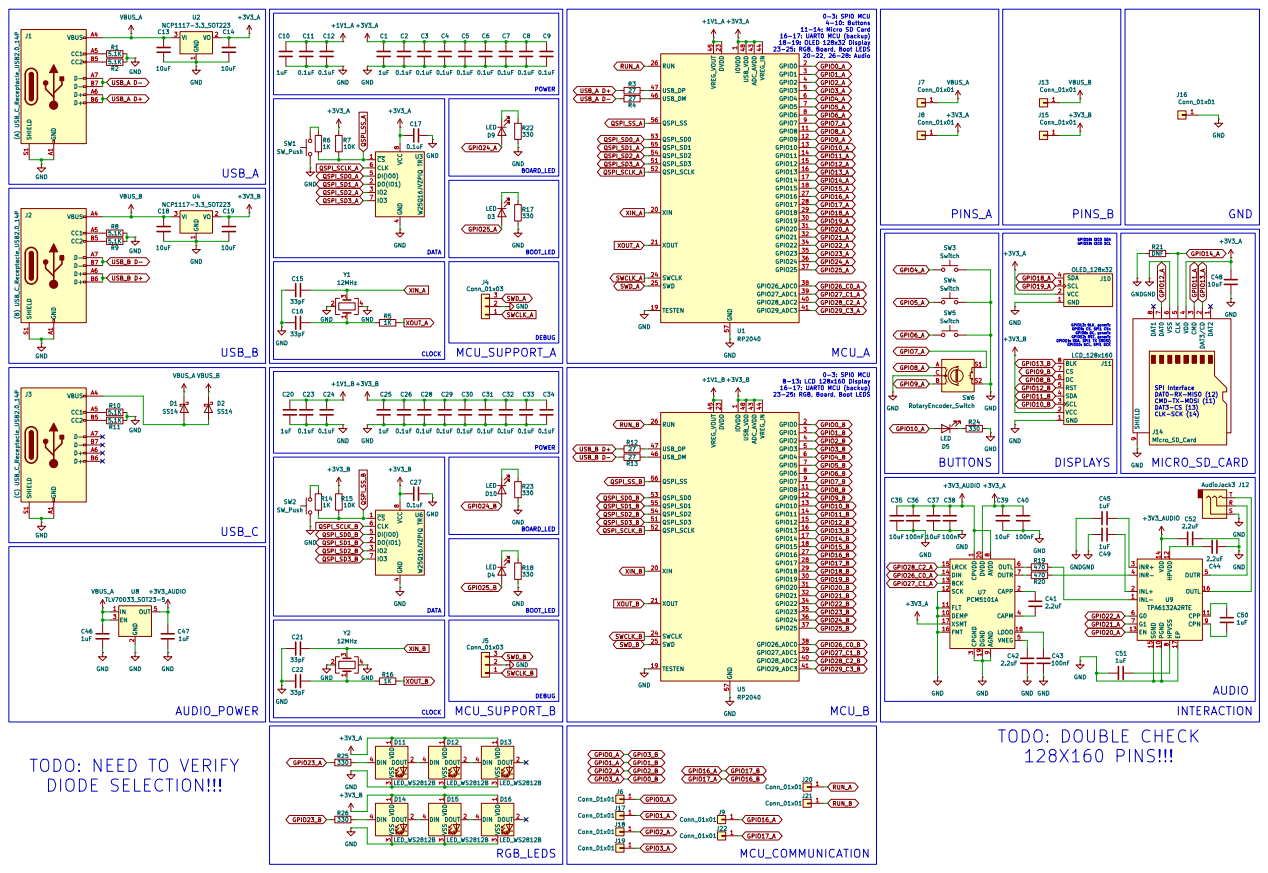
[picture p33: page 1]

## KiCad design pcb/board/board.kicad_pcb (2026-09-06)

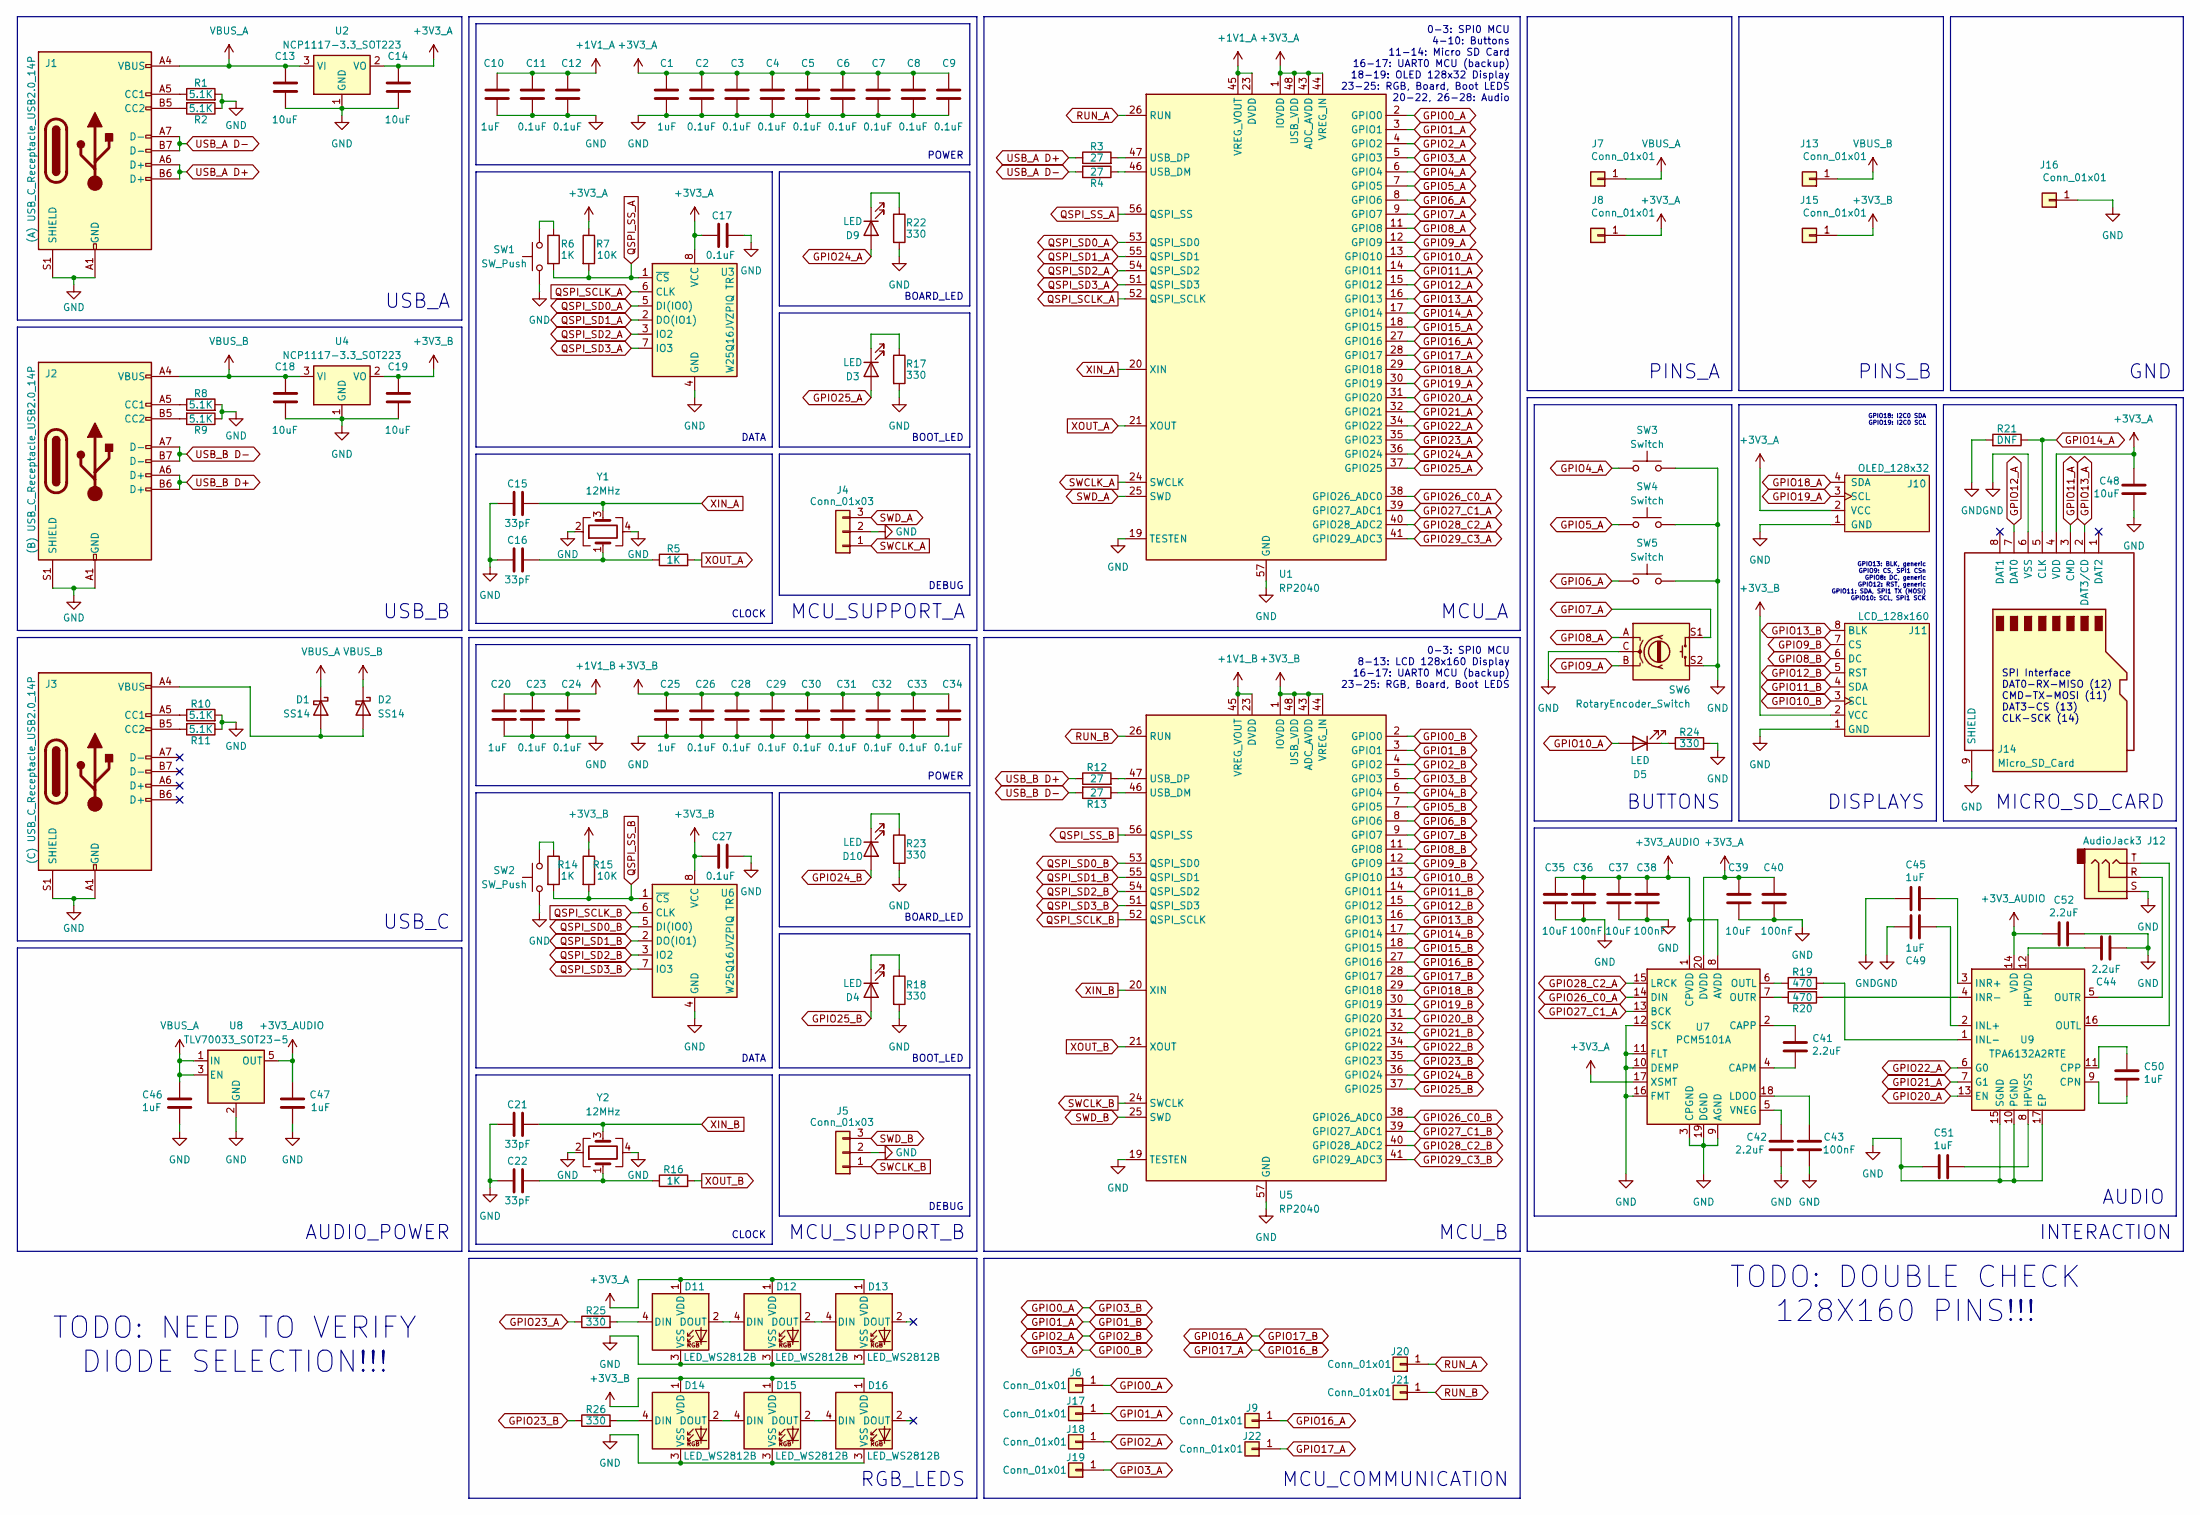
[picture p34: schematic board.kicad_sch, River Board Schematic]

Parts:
C1, C10, C20, C25, C45, C46, C47, C49, C50, C51: 1uF; C_0402_1005Metric
C2, C3, C4, C5, C6, C7, C8, C9, C11, C12, C17, C23, C24, C26, C27, C28, C29, C30, C31, C32, C33, C34: 0.1uF; C_0402_1005Metric
C13, C14, C18, C19: 10uF; C_0603_1608Metric
C15, C16, C21, C22: 33pF; C_0402_1005Metric
C35, C37, C39, C48: 10uF; C_0402_1005Metric
C36, C38, C40, C43: 100nF; C_0402_1005Metric
C41, C42, C44, C52: 2.2uF; C_0402_1005Metric
D1, D2: SS14; D_SMA
D3, D4, D5, D9, D10: LED; LED_0603_1608Metric
D11, D12, D13, D14, D15, D16: LED_WS2812B
J1: (A) USB_C_Receptacle_USB2.0_14P; USB_C_Receptacle_HRO_TYPE-C-31-M-12
J2: (B) USB_C_Receptacle_USB2.0_14P; USB_C_Receptacle_HRO_TYPE-C-31-M-12
J3: (C) USB_C_Receptacle_USB2.0_14P; USB_C_Receptacle_HRO_TYPE-C-31-M-12
J4, J5: Conn_01x03; PinHeader_1x03_P2.54mm_Vertical
J6, J9, J17, J18, J19, J20, J21, J22: Conn_01x01; TestPoint_Pad_D1.0mm
J7, J13: Conn_01x01; TestPoint_Pad_1.0x1.0mm
J8, J15, J16: Conn_01x01; PinHeader_1x01_P2.54mm_Vertical
J10: OLED_128x32
J11: LCD_128x160
J12: AudioJack3; Jack_3.5mm_CUI_SJ-3523-SMT_Horizontal
J14: Micro_SD_Card; microSD_HC_Molex_47219-2001
R1, R2, R8, R9, R10, R11: 5.1K; R_0402_1005Metric
R3, R4, R12, R13: 27; R_0402_1005Metric
R5, R6, R14, R16: 1K; R_0402_1005Metric
R7, R15: 10K; R_0402_1005Metric
R17, R18, R22, R23, R24, R25, R26: 330; R_0402_1005Metric
R19, R20: 470; R_0402_1005Metric
R21: DNF; R_0402_1005Metric
SW1, SW2: SW_Push; SW_Push_SPST_NO_Alps_SKRK
SW3, SW4, SW5: Switch; SW_Cherry_MX_1.00u_PCB
SW6: RotaryEncoder_Switch; RotaryEncoder_Alps_EC11E-Switch_Vertical_H20mm
U1, U5: RP2040; QFN-56-1EP_7x7mm_P0.4mm_EP3.2x3.2mm
U2, U4: NCP1117-3.3_SOT223; SOT-223-3_TabPin2
U3, U6: W25Q16JVZPIQ TR; Winbond_USON-8-1EP_3x2mm_P0.5mm_EP0.2x1.6mm
U7: PCM5101A; TSSOP-20_4.4x6.5mm_P0.65mm
U8: TLV70033_SOT23-5; SOT-23-5
U9: TPA6132A2RTE; WQFN-16-1EP_3x3mm_P0.5mm_EP1.6x1.6mm_ThermalVias
Y1, Y2: 12MHz; Crystal_SMD_3225-4Pin_3.2x2.5mm

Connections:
+1V1_A: C10.1, C11.1, C12.1, U1.23 (DVDD), U1.45 (VREG_VOUT), U1.50 (DVDD)
+1V1_B: C20.1, C23.1, C24.1, U5.23 (DVDD), U5.45 (VREG_VOUT), U5.50 (DVDD)
+3V3_A: C1.1, C2.1, C3.1, C4.1, C5.1, C6.1, C7.1, C8.1, C9.1, C14.1, C17.1, C39.1, C40.1, C48.1, D11.1 (VDD), D12.1 (VDD), D13.1 (VDD), J8.1, J10.2 (VCC), J14.4 (VDD), R7.1, U1.1 (IOVDD), U1.10 (IOVDD), U1.22 (IOVDD), U1.33 (IOVDD), U1.42 (IOVDD), U1.43 (ADC_AVDD), U1.44 (VREG_IN), U1.48 (USB_VDD), U1.49 (IOVDD), U2.2 (VO), U3.8 (VCC), U7.17 (XSMT), U7.20 (DVDD)
+3V3_AUDIO: C35.1, C36.1, C37.1, C38.1, C47.1, C52.1, U7.1 (CPVDD), U7.8 (AVDD), U8.5 (OUT), U9.14 (VDD)
+3V3_B: C19.1, C25.1, C26.1, C27.1, C28.1, C29.1, C30.1, C31.1, C32.1, C33.1, C34.1, D14.1 (VDD), D15.1 (VDD), D16.1 (VDD), J11.2 (VCC), J15.1, R15.1, U4.2 (VO), U5.1 (IOVDD), U5.10 (IOVDD), U5.22 (IOVDD), U5.33 (IOVDD), U5.42 (IOVDD), U5.43 (ADC_AVDD), U5.44 (VREG_IN), U5.48 (USB_VDD), U5.49 (IOVDD), U6.8 (VCC)
GND: C1.2, C2.2, C3.2, C4.2, C5.2, C6.2, C7.2, C8.2, C9.2, C10.2, C11.2, C12.2, C13.2, C14.2, C15.1, C16.1, C17.2, C18.2, C19.2, C20.2, C21.1, C22.1, C23.2, C24.2, C25.2, C26.2, C27.2, C28.2, C29.2, C30.2, C31.2, C32.2, C33.2, C34.2, C35.2, C36.2, C37.2, C38.2, C39.2, C40.2, C42.2, C43.2, C44.2, C45.1, C46.2, C47.2, C48.2, C49.1, C51.1, C52.2, D11.3 (VSS), D12.3 (VSS), D13.3 (VSS), D14.3 (VSS), D15.3 (VSS), D16.3 (VSS), J1.A1 (GND), J1.A12 (GND), J1.B1 (GND), J1.B12 (GND), J1.S1 (SHIELD), J2.A1 (GND), J2.A12 (GND), J2.B1 (GND), J2.B12 (GND), J2.S1 (SHIELD), J3.A1 (GND), J3.A12 (GND), J3.B1 (GND), J3.B12 (GND), J3.S1 (SHIELD), J4.2, J5.2, J10.1 (GND), J11.1 (GND), J12.S, J14.6 (VSS), J14.9 (SHIELD), J16.1, R1.2, R2.1, R8.2, R9.1, R10.2, R11.1, R17.2, R18.2, R21.2, R22.2, R23.2, R24.2, SW1.1, SW2.1, SW3.2, SW4.2, SW5.2, SW6.C, SW6.S2, U1.19 (TESTEN), U1.57 (GND), U2.1 (GND), U3.4 (GND), U4.1 (GND), U5.19 (TESTEN), U5.57 (GND), U6.4 (GND), U7.3 (CPGND), U7.9 (AGND), U7.10 (DEMP), U7.11 (FLT), U7.12 (SCK), U7.16 (FMT), U7.19 (DGND), U8.2 (GND), U9.10 (PGND), U9.15 (SGND), U9.17 (EP), Y1.2, Y1.4, Y2.2, Y2.4
GPIO0_A: J6.1, U1.2 (GPIO0), U5.5 (GPIO3)
GPIO0_B: J19.1, U1.5 (GPIO3), U5.2 (GPIO0)
GPIO1_A: J17.1, U1.3 (GPIO1), U5.3 (GPIO1)
GPIO2_A: J18.1, U1.4 (GPIO2), U5.4 (GPIO2)
GPIO4_A: SW3.1, U1.6 (GPIO4)
GPIO4_B: U5.6 (GPIO4)
GPIO5_A: SW4.1, U1.7 (GPIO5)
GPIO5_B: U5.7 (GPIO5)
GPIO6_A: SW5.1, U1.8 (GPIO6)
GPIO6_B: U5.8 (GPIO6)
GPIO7_A: SW6.S1, U1.9 (GPIO7)
GPIO7_B: U5.9 (GPIO7)
GPIO8_A: SW6.A, U1.11 (GPIO8)
GPIO8_B: J11.6 (DC), U5.11 (GPIO8)
GPIO9_A: SW6.B, U1.12 (GPIO9)
GPIO9_B: J11.7 (CS), U5.12 (GPIO9)
GPIO10_A: D5.2 (A), U1.13 (GPIO10)
GPIO10_B: J11.3 (SCL), U5.13 (GPIO10)
GPIO11_A: J14.3 (CMD), U1.14 (GPIO11)
GPIO11_B: J11.4 (SDA), U5.14 (GPIO11)
GPIO12_A: J14.7 (DAT0), U1.15 (GPIO12)
GPIO12_B: J11.5 (RST), U5.15 (GPIO12)
GPIO13_A: J14.2 (DAT3/CD), U1.16 (GPIO13)
GPIO13_B: J11.8 (BLK), U5.16 (GPIO13)
GPIO14_A: J14.5 (CLK), R21.1, U1.17 (GPIO14)
GPIO14_B: U5.17 (GPIO14)
GPIO15_A: U1.18 (GPIO15)
GPIO15_B: U5.18 (GPIO15)
GPIO16_A: J9.1, U1.27 (GPIO16), U5.28 (GPIO17)
GPIO16_B: J22.1, U1.28 (GPIO17), U5.27 (GPIO16)
GPIO18_A: J10.4 (SDA), U1.29 (GPIO18)
GPIO18_B: U5.29 (GPIO18)
GPIO19_A: J10.3 (SCL), U1.30 (GPIO19)
GPIO19_B: U5.30 (GPIO19)
GPIO20_A: U1.31 (GPIO20), U9.13 (EN)
GPIO20_B: U5.31 (GPIO20)
GPIO21_A: U1.32 (GPIO21), U9.7 (G1)
GPIO21_B: U5.32 (GPIO21)
GPIO22_A: U1.34 (GPIO22), U9.6 (G0)
GPIO22_B: U5.34 (GPIO22)
GPIO23_A: R25.1, U1.35 (GPIO23)
GPIO23_B: R26.1, U5.35 (GPIO23)
GPIO24_A: D9.2 (A), U1.36 (GPIO24)
GPIO24_B: D10.2 (A), U5.36 (GPIO24)
GPIO25_A: D3.2 (A), U1.37 (GPIO25)
GPIO25_B: D4.2 (A), U5.37 (GPIO25)
GPIO26_C0_A: U1.38 (GPIO26_ADC0), U7.14 (DIN)
GPIO26_C0_B: U5.38 (GPIO26_ADC0)
GPIO27_C1_A: U1.39 (GPIO27_ADC1), U7.13 (BCK)
GPIO27_C1_B: U5.39 (GPIO27_ADC1)
GPIO28_C2_A: U1.40 (GPIO28_ADC2), U7.15 (LRCK)
GPIO28_C2_B: U5.40 (GPIO28_ADC2)
GPIO29_C3_A: U1.41 (GPIO29_ADC3)
GPIO29_C3_B: U5.41 (GPIO29_ADC3)
unnamed: C16.2, R5.1, Y1.1
unnamed: C22.2, R16.1, Y2.1
unnamed: D1.2 (A), D2.2 (A), J3.A4 (VBUS), J3.A9 (VBUS), J3.B4 (VBUS), J3.B9 (VBUS)
unnamed: D3.1 (K), R17.1
unnamed: D4.1 (K), R18.1
unnamed: D5.1 (K), R24.1
unnamed: D9.1 (K), R22.1
unnamed: D10.1 (K), R23.1
unnamed: D11.4 (DIN), R25.2
unnamed: D11.2 (DOUT), D12.4 (DIN)
unnamed: D12.2 (DOUT), D13.4 (DIN)
unnamed: D14.4 (DIN), R26.2
unnamed: D14.2 (DOUT), D15.4 (DIN)
unnamed: D15.2 (DOUT), D16.4 (DIN)
unnamed: J1.A5 (CC1), R1.1
unnamed: J1.B5 (CC2), R2.2
unnamed: J2.A5 (CC1), R8.1
unnamed: J2.B5 (CC2), R9.2
unnamed: J3.A5 (CC1), R10.1
unnamed: J3.B5 (CC2), R11.2
unnamed: R6.1, SW1.2
unnamed: R14.1, SW2.2
unnamed: R4.1, U1.46 (USB_DM)
unnamed: R3.2, U1.47 (USB_DP)
unnamed: R13.1, U5.46 (USB_DM)
unnamed: R12.2, U5.47 (USB_DP)
unnamed: C41.2, U7.4 (CAPM)
unnamed: C41.1, U7.2 (CAPP)
unnamed: C43.1, U7.18 (LDOO)
unnamed: R19.1, U7.6 (OUTL)
unnamed: R20.1, U7.7 (OUTR)
unnamed: C42.1, U7.5 (VNEG)
unnamed: C50.2, U9.9 (CPN)
unnamed: C50.1, U9.11 (CPP)
unnamed: C44.1, U9.12 (HPVDD)
unnamed: C51.2, U9.8 (HPVSS)
unnamed: C49.2, U9.2 (INL+)
unnamed: R19.2, U9.1 (INL-)
unnamed: C45.2, U9.3 (INR+)
unnamed: R20.2, U9.4 (INR-)
unnamed: J12.T, U9.16 (OUTL)
unnamed: J12.R, U9.5 (OUTR)
QSPI_SCLK_A: U1.52 (QSPI_SCLK), U3.6 (CLK)
QSPI_SCLK_B: U5.52 (QSPI_SCLK), U6.6 (CLK)
QSPI_SD0_A: U1.53 (QSPI_SD0), U3.5 (DI(IO0))
QSPI_SD0_B: U5.53 (QSPI_SD0), U6.5 (DI(IO0))
QSPI_SD1_A: U1.55 (QSPI_SD1), U3.2 (DO(IO1))
QSPI_SD1_B: U5.55 (QSPI_SD1), U6.2 (DO(IO1))
QSPI_SD2_A: U1.54 (QSPI_SD2), U3.3 (IO2)
QSPI_SD2_B: U5.54 (QSPI_SD2), U6.3 (IO2)
QSPI_SD3_A: U1.51 (QSPI_SD3), U3.7 (IO3)
QSPI_SD3_B: U5.51 (QSPI_SD3), U6.7 (IO3)
QSPI_SS_A: R6.2, R7.2, U1.56 (QSPI_SS), U3.1 (~CS)
QSPI_SS_B: R14.2, R15.2, U5.56 (QSPI_SS), U6.1 (~CS)
RUN_A: J20.1, U1.26 (RUN)
RUN_B: J21.1, U5.26 (RUN)
SWCLK_A: J4.1, U1.24 (SWCLK)
SWCLK_B: J5.1, U5.24 (SWCLK)
SWD_A: J4.3, U1.25 (SWD)
SWD_B: J5.3, U5.25 (SWD)
USB_A D+: J1.A6 (D+), J1.B6 (D+), R3.1
USB_A D-: J1.A7 (D-), J1.B7 (D-), R4.2
USB_B D+: J2.A6 (D+), J2.B6 (D+), R12.1
USB_B D-: J2.A7 (D-), J2.B7 (D-), R13.2
VBUS_A: C13.1, C46.1, D1.1 (K), J1.A4 (VBUS), J1.A9 (VBUS), J1.B4 (VBUS), J1.B9 (VBUS), J7.1, U2.3 (VI), U8.1 (IN), U8.3 (EN)
VBUS_B: C18.1, D2.1 (K), J2.A4 (VBUS), J2.A9 (VBUS), J2.B4 (VBUS), J2.B9 (VBUS), J13.1, U4.3 (VI)
XIN_A: C15.2, U1.20 (XIN), Y1.3
XIN_B: C21.2, U5.20 (XIN), Y2.3
XOUT_A: R5.2, U1.21 (XOUT)
XOUT_B: R16.2, U5.21 (XOUT)

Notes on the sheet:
MICRO_SD_CARD
MCU_SUPPORT_A
PINS_B
CLOCK
BOOT_LED
BUTTONS
RGB_LEDS
DATA
AUDIO
USB_C
POWER
USB_B
MCU_A
MCU_B
DEBUG
INTERACTION
MCU_SUPPORT_B
BOARD_LED
USB_A
DISPLAYS
PINS_A
GND
MCU_COMMUNICATION
AUDIO_POWER
GPIO13: BLK, generic GPIO9: CS, SPI1 CSn GPIO8: DC, generic GPIO12: RST, generic GPIO11: SDA, SPI1 TX (MOSI) GPIO10: SCL, SPI1 SCK
0-3: SPI0 MCU 4-10: Buttons 11-14: Micro SD Card 16-17: UART0 MCU (backup) 18-19: OLED 128x32 Display 23-25: RGB, Board, Boot LEDS 20-22, 26-28: Audio
0-3: SPI0 MCU 8-13: LCD 128x160 Display 16-17: UART0 MCU (backup) 23-25: RGB, Board, Boot LEDS
GPIO18: I2C0 SDA GPIO19: I2C0 SCL
TODO: NEED TO VERIFY DIODE SELECTION!!!
TODO: DOUBLE CHECK 128X160 PINS!!!
SPI Interface DAT0-RX-MISO (12) CMD-TX-MOSI (11) DAT3-CS (13) CLK-SCK (14)

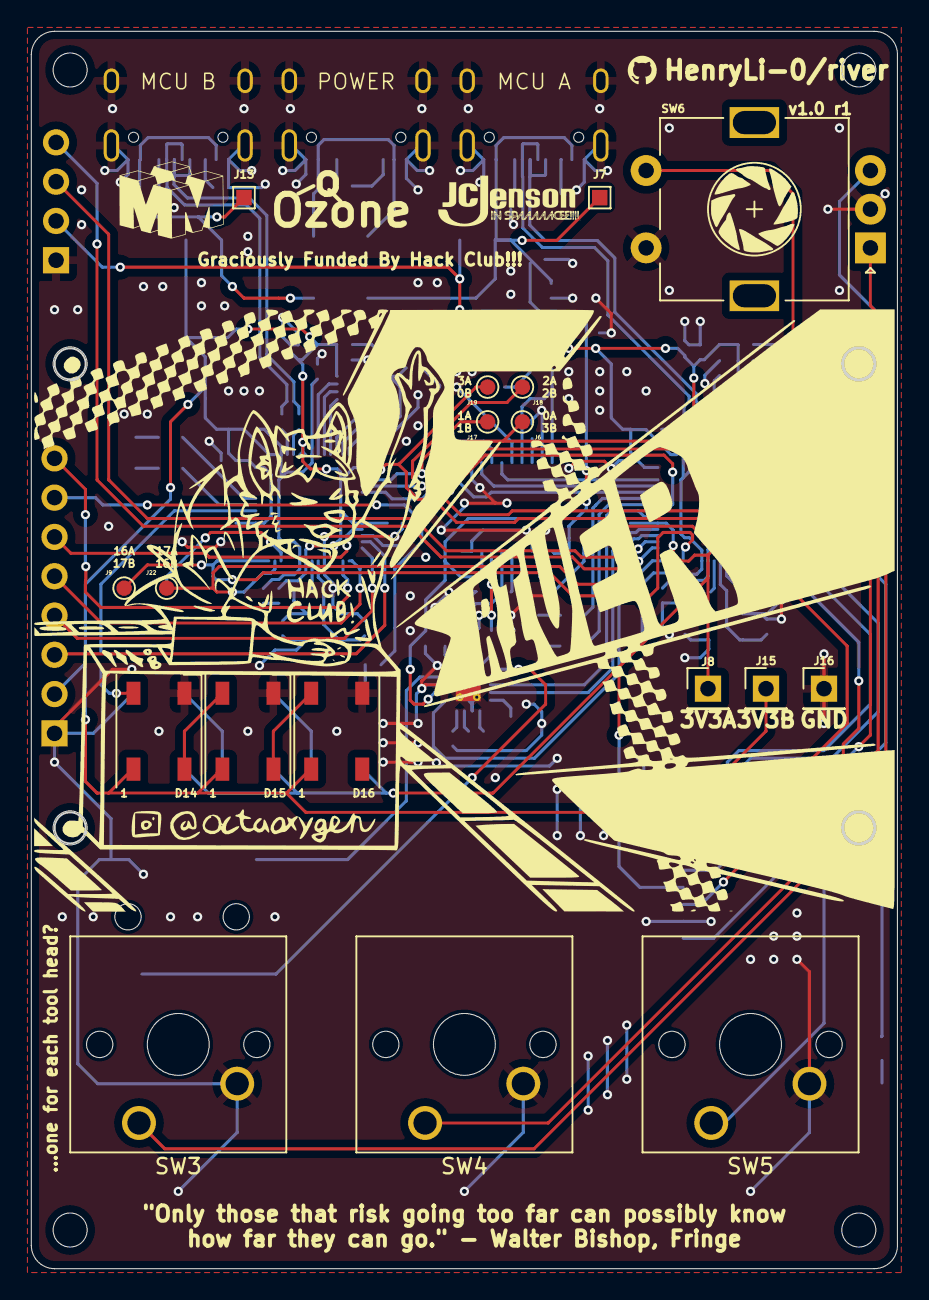
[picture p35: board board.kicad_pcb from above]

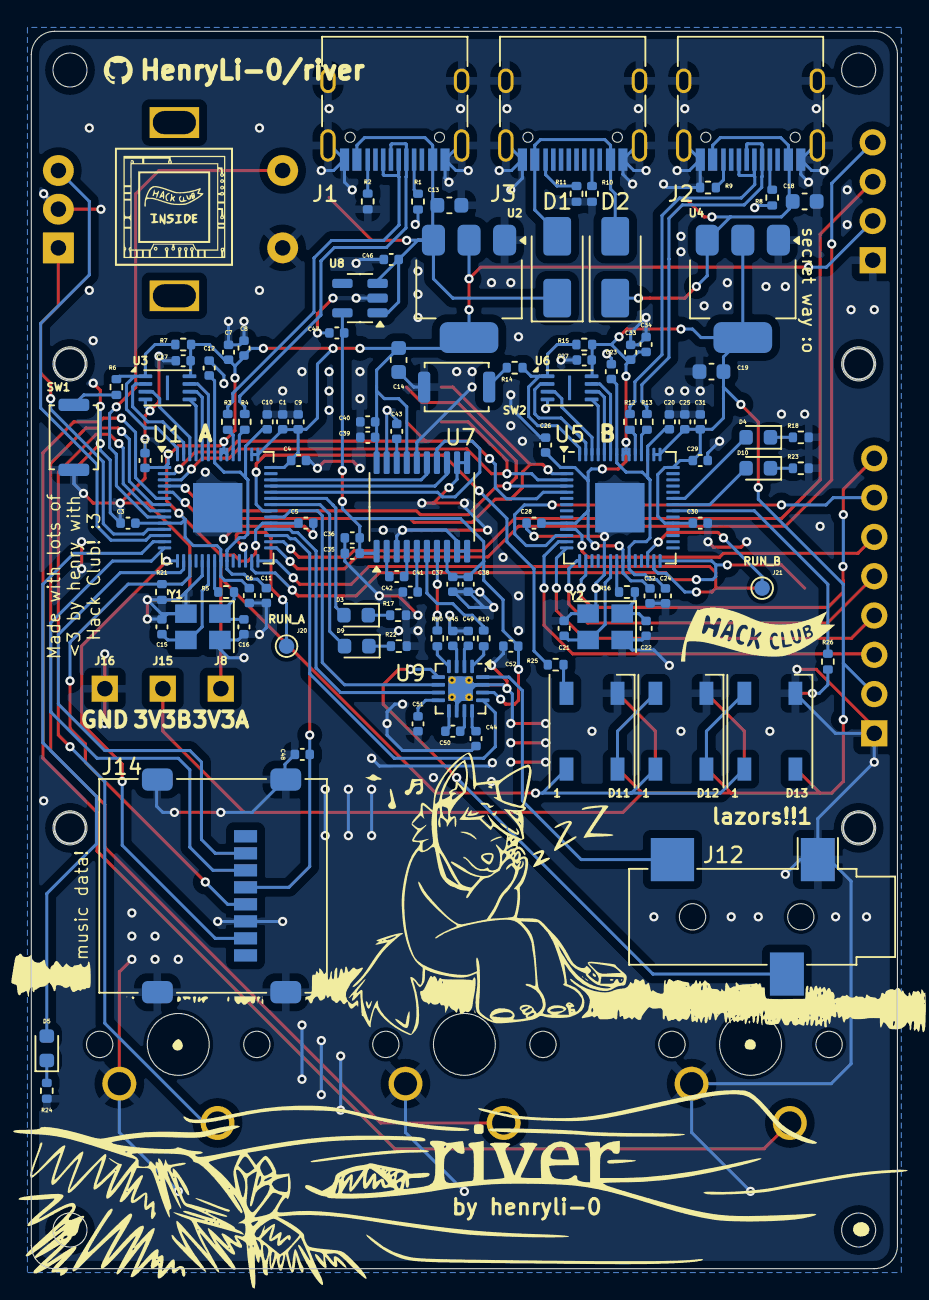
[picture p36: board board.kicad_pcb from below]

Board: 2 copper layers, 56.0 x 80.0 mm, 128 parts (108 on the bottom side), 109 nets.

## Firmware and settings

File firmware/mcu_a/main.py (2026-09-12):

import board
import digitalio
import busio
import time
import os

import storage
import sdcardio

import displayio
import terminalio
import adafruit_displayio_ssd1306 #??? idk maybe

import audiomp3
import audiopwmio

# ??? still need to understand these docs

'''DOUBLE CHECK THESE PINS'''
class Constants:
    BUTTONS = [board.GP4, board.GP5, board.GP6]

    class GPU_SPI:
        SCK = board.GP0
        MOSI = board.GP1
        MISO = board.GP2
        CS = board.GP3

    class GPU_UART:
        TX = board.GP16
        RX = board.GP17

    class SD:
        SCK = board.GP11
        MOSI = board.GP12
        MISO = board.GP13
        CS = board.GP14

        DIR = "/sd" # ???
        EXTENSIONS = [".mp3", ".wav"]

    class OLED:
        SCL = board.GP18
        SDA = board.GP19

    class LEDS:
        RGB = board.GP23
        BOARD = board.GP24
        BOOT = board.GP25

    class AUDIO:
        pass

led = digitalio.DigitalInOut(Constants.LEDS.BOOT)
led.direction = digitalio.Direction.OUTPUT
led.value = True

class MCU_A:
    def __init__(self):
        # self.setupSPI()
        self.setupUART()

    # setup comms (in theory)
    def setupUART(self):
        self.uart = busio.UART(
            Constants.GPU_UART.TX,
            Constants.GPU_UART.RX # where does baudrate come in
        )
    def setupSPI(self):
        self.spi = busio.SPI(
            Constants.GPU_SPI.SCK,
            Constants.GPU_SPI.MOSI,
            Constants.GPU_SPI.MISO
        )
    def send(self):
        if self.uart is None:
            self.setupUART()
        # ???

    def setupSD(self):
        self.sdSPI = busio.SPI(
            Constants.SD.SCK,
            Constants.SD.MOSI,
            Constants.SD.MISO
        )
        self.sd = sdcardio.SDCard(
            self.sdSPI,
            Constants.SD.CS # where does baudrate come in
        )

        '''TODO mount and read the sd card???'''


    def setupPlay(self):
        self.pause = False
        self.songID = 0
        # pick first song idk

    def play(self):
        self.pause = False

    def stop(self):
        self.pause = False
        # ???
    

mcu = MCU_A()

# some update loop for the user stuff

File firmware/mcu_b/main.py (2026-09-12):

'''this should be rewritten in c for better performance!'''

import board
import digitalio
import busio
import time

import displayio

'''DOUBLE CHECK THESE PINS'''
class Constants:
    class CPU_SPI:
        SCK = board.GP0
        MOSI = board.GP2
        MISO = board.GP1
        CS = board.GP3

    class CPU_UART:
        TX = board.GP17
        RX = board.GP16

    class TFT:
        DC = board.GP8
        CS = board.GP9
        SCK = board.GP10
        MOSI = board.GP11
        RST = board.GP12
        BL = board.GP13

    class LEDS:
        RGB = board.GP23
        BOARD = board.GP24
        BOOT = board.GP25

led = digitalio.DigitalInOut(Constants.LEDS.BOOT)
led.direction = digitalio.Direction.OUTPUT
led.value = True

class MCU_B:
    def __init__(self):
        # self.setupSPI()
        self.setupUART()

        self.setupDisplay()

    # setup comms (in theory)
    def setupUART(self):
        self.uart = busio.UART(
            Constants.CPU_UART.TX,
            Constants.CPU_UART.RX # where does baudrate come in
        )
    def setupSPI(self):
        self.spi = busio.SPI(
            Constants.CPU_SPI.SCK,
            Constants.CPU_SPI.MOSI,
            Constants.CPU_SPI.MISO
        )
    def send(self):
        if self.uart is None:
            self.setupUART()
        # ???

    def setupDisplay(self):
        self.displaySPI = busio.SPI(
            Constants.TFT.SCK,
            MOSI = Constants.TFT.MOSI
        )
        self.display = displayio.FourWire( #??? idk if this is correct
            self.displaySPI,
            command = Constants.TFT.DC,
            chip_select = Constants.TFT.CS,
            reset = Constants.TFT.RST,
        )

mcu = MCU_B()

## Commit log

2026-07-31 07302026 - display sourced and starting cad!
2026-08-01 07312026 - even more cad work and sourcing stuff!
2026-08-01 start kicad!
    [board.kicad_pcb, board.kicad_sch]
2026-08-02 single rp2040 stuffs!
    [board.kicad_sch]
2026-08-02 08012026 - tons of schematic work!
    [board.kicad_pcb, board.kicad_sch]
2026-08-02 add connector pins to the schematic!
    [board.kicad_sch]
2026-08-03 add display footprint/symbol and switches/encoder wiring!
    [board.kicad_sch]
2026-08-03 08022026 - more schematic work!
    [board.kicad_sch]
2026-08-04 add audio and sd card stuff
    [board.kicad_sch]
2026-08-04 add labels for display pins (and added leds!)
    [board.kicad_sch]
2026-08-05 reassign pins and mcu spi connection (and uart backup!)!
    [board.kicad_sch]
2026-08-05 08032026 - even more schematic work!
2026-08-06 08052026 - reassign pins and more audio stuff!
    [board.kicad_sch]
2026-08-07 footprint assigning and wrapping up schematic work!
    [board.kicad_sch]
2026-08-07 08062026 - wrapping up schematic work!
    [board.kicad_sch]
2026-08-17 start pcb work! mcu_a wired!
    [board.kicad_pcb, board.kicad_sch]
2026-08-17 08162026 - start pcb! (layout and both mcus wired!)
    [board.kicad_pcb, board.kicad_sch]
2026-08-18 audio stuff wired together!
    [board.kicad_pcb]
2026-08-18 08172026 - pcb work continues! (audio and most mcu pin connections!)
    [board.kicad_pcb, board.kicad_sch]
2026-08-19 leds and more connections!
    [board.kicad_pcb, board.kicad_sch]
2026-08-19 08192026 - starting to wrap up pcb work!
    [board.kicad_pcb, board.kicad_sch]
2026-08-22 08212026 - catch up and tons of silkscreen art and fun!
    [board.kicad_pcb]
2026-08-23 more silkscreen art! and back to wrapping up
    [board.kicad_pcb]
2026-08-24 08232026 - exporting and back to again
    [board-B_Cu.gbl, board-B_Mask.gbs, board-B_Paste.gbp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]
2026-08-26 audio jack moved to bottom layer!
    [Same_Sky_SJ-3523-SMT-TR.step, board.kicad_pcb]
2026-08-26 micro sd card slot moved to bottom layer!
    [board.kicad_pcb]
2026-08-26 more ground vias and some silkscreen text fixes!
    [board.kicad_pcb, board.kicad_sch]
2026-08-27 lots of silkscreen and art fixes!
    [board.kicad_pcb]
2026-08-27 08262026 - lots of boards fixes and exporting!
    [board-B_Cu.gbl, board-B_Mask.gbs, board-B_Paste.gbp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]
2026-08-28 08272026 - jlcpcb shenanigans and bom stuff!
    [board-JLCPCB Assembly Order.xls]
2026-09-06 update micro sd card footprint
    [472192001.stp, board.kicad_pcb, board.kicad_sch]
2026-09-06 board added to jlcpcb! (placement and all!)
    [board-B_Cu.gbl, board-B_Mask.gbs, board-B_Paste.gbp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]
2026-09-06 09052026 - update micro sd card footprint and pcba added to jlcpcb cart!
2026-09-11 09102026 - wrapping up cad stuff! also added banner and license!
    [board.step]
2026-09-12 tons of docs, readme stuffs, bom, step file, and more!
    [BOM.csv, river-Full Assembly-2026-09-11 23-05-53.step]
2026-09-12 random kicad lock file (kicad deleted it)
2026-09-14 added kicad pcb picture and schematic pdf
2026-09-27 09262026 - ordering! (or not...)
    [board-JLCPCB Assembly Order.xls]
